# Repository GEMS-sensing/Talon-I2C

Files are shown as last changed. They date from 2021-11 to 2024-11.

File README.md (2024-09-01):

<!-- [![DOI](https://zenodo.org/badge/678911830.svg)](https://zenodo.org/doi/10.5281/zenodo.13377368) -->

# Talon-I2C
Talon daughterboard for [Flight data logger](https://github.com/GEMS-sensing/DFM_-_Flight?tab=readme-ov-file). Designed to interface with [Kestrel](https://github.com/GEMS-sensing/Project-Kestrel) main board. This board is designed to provide data logger with support to interface with I2C based sensors - a common interface for open source sensors.

# Repo Roadmap
#### [Documents](Documents/) 

General document and image storage for repo and README

#### [Hardware](Hardware/)

Current board files (Eagle), Bill of Materials (BoM), and other design documents

#### [Production](Production/)

Contains the various Gerber and pick and place files required to have the Printed Circuit Boards (PCBs) manufactured or populated 

#### [Software](Software/)

The software associated with the piece of hardware, this is usually diagnostic software used for verifying or investigating the hardware

<!-- #### [Mechanical](Mechanical/)

Mechanical design files and assembly documents -->

<!-- #### [Testing](Testing/)

Scripts and results from the testing process and development process. Contains more detailed information about documented issues among other testing. 
 -->

## Overview
* **Type:** Talon
* **Interfaces:** SDI-12
* **Release Version:** v2.1 - 2022/04/25

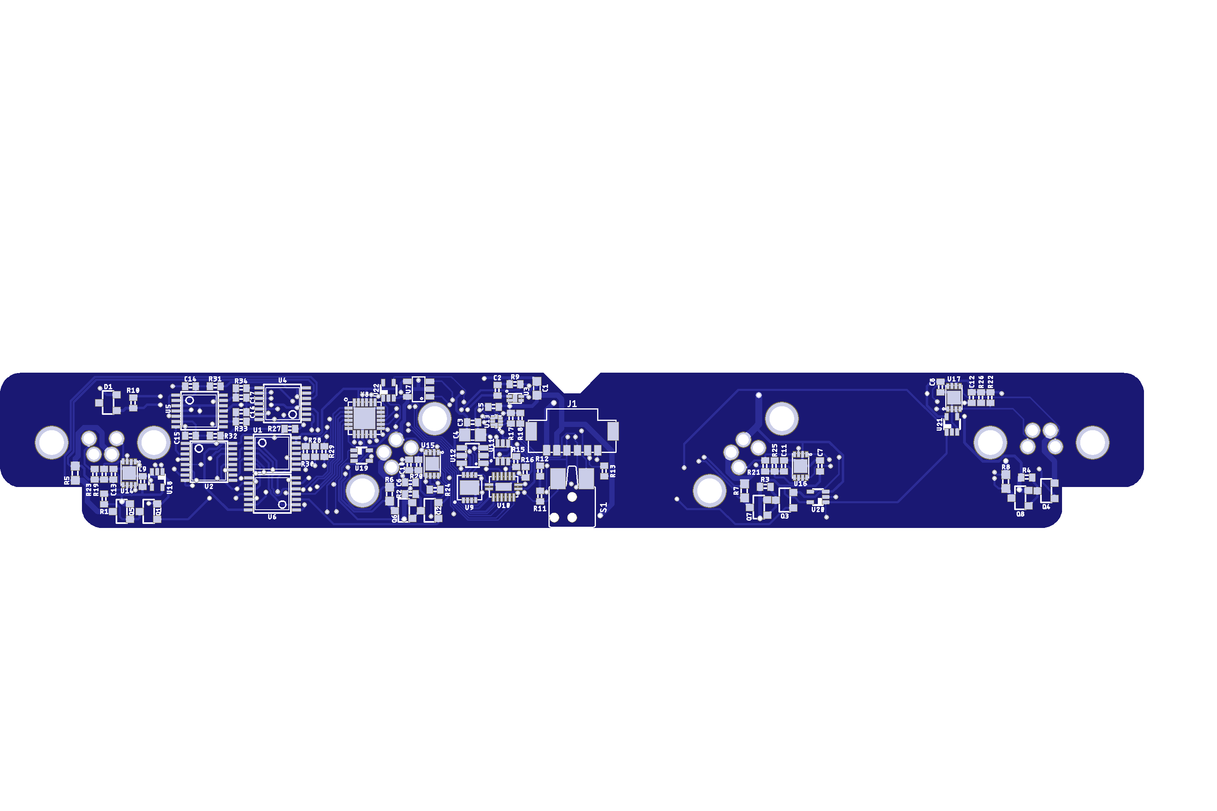
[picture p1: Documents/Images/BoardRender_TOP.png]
PCB render image, top


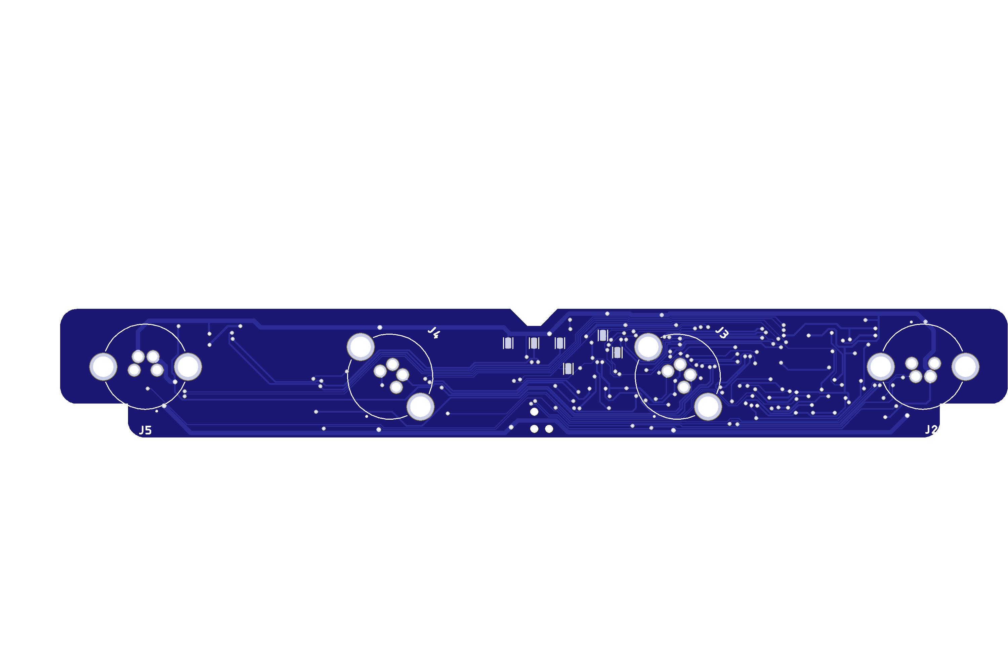
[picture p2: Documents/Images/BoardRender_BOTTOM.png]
PCB render image, bottom


<!-- ![Haar v0.0 - Bottom](Documents/Images/Haar_0v0_Bottom_Cropped.jpg) -->

## Features
### On-Board
* I2C ports (x4)
	* Isolated I2C bus for each port with line driver to deal with long, high capacitance sensor cables
* Port level current limit
	* Custom designed automatic current limit 
	* support for current and voltage measurement for each port
* Data and power control for each port
* Internal and external isolated I2C buses 
* EEPROM with UUID built in - can store additional values defined by firmware to track offsets, etc
* ESD protected inputs

<!-- ### Interface
* I<sup>2</sup>C
* M12 circular connector  -->

<!-- <picture>
  <source media="(prefers-color-scheme: dark)" srcset="Documents/Pinout_LIGHT.png">
  <img alt="Haar Connector Pinout" src="Documents/Pinout.png">
</picture> -->

<!-- ## Specifications
* **Voltage - Supply:** 3.3V
* **Voltage - Logic:** 3.3V
* **Input Current (Avg, 1s period): 30.95&mu;A @ 3.3V**
* **Input Current (Avg, 5s period): 107.43&mu;A @ 3.3V**
* **Input Current (Max): 0.45mA @ 3.3V**

#### Sensor
**Temperature** [^1]
* Range: -40 ~ 125°C 
* Accuracy: &plusmn; 0.2°C
* Repeatability: &plusmn; 0.04°C

**Pressure** [^2]
* Range: 300 ~ 1200 hPa  
* Accuracy: &plusmn; 1 hPa
* Repeatability: &plusmn; 0.06 hPa

**Humidity** [^1]
* Range: 0 ~ 100%
* Accuracy: &plusmn; 2%
* Repeatability: 0.08%

[^1]: [SHT31 Datasheet](https://sensirion.com/media/documents/213E6A3B/63A5A569/Datasheet_SHT3x_DIS.pdf)
[^2]: [DPS368 Datasheet](https://www.infineon.com/dgdl/Infineon-DPS368-DS-v01_00-EN.pdf?fileId=5546d46269e1c019016a0c45105d4b40) -->

<!-- ## Version History

`v0.0` - Initial primal version with screw terminal

`v0.1` - Initial 'hard mount' version, using M12 connector

`v1.0` - Removed pullup select[^3], added logic level buffer and voltage reg on input

`v1.1` - Moved via away from connector pads to prevent bridging when soldering 

`v2.0` - Fixed issue with address select jumper[^3] -->

<!-- ## Jumper Settings 

> [!IMPORTANT]
> Jumper settings valid for version `v2.0` and beyond[^3]

[^3]: See Errata

**Configuration Jumpers**
| Jumper | Purpose | Open | Closed | Default | 
| --- | --- | --- | --- | ----- |
| `JP1` | I<sup>2</sup>C Address Select | Base Address<sup>&dagger;</sup> | Alt Address<sup>&Dagger;</sup> | Open |

&dagger; SHT31 = `0x44`, DPS368 = `0x76`

&Dagger; SHT31 = `0x44`, DPS368 = `0x77`
 -->

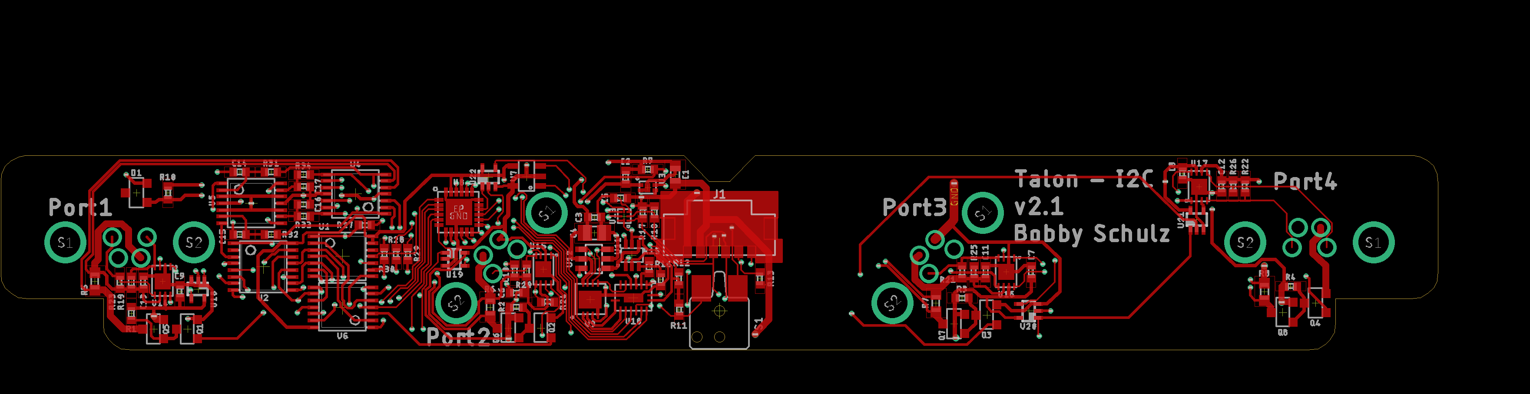
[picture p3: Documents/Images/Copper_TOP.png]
PCB trace CAD image, top


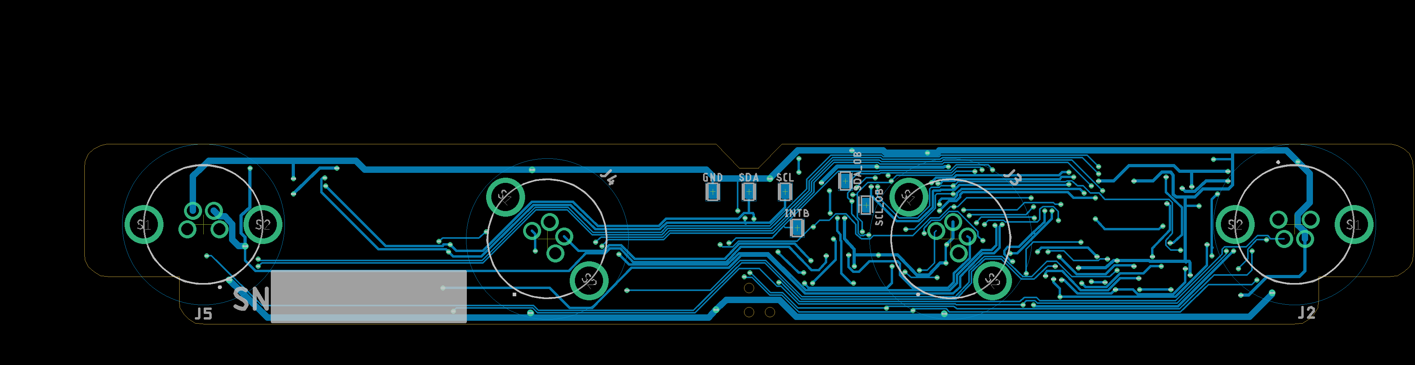
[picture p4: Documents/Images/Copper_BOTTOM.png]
PCB trace CAD, bottom


## Known Issues/Errata

None
<!-- #### Solder Jumper Stencil

**Version Affected:** All

**Issue:** Solar input does not support very low impedance sources (e.g. lead acid battery) - see details in issue [#20](https://github.com/GEMS-sensing/Project-Kestrel/issues/20)

**Workaround:** 

* Avoid use of low impedance batteries for input
* Include series impedance to prevent current spikes (not desirable)
* Perform board patch described in issue [#20](https://github.com/GEMS-sensing/Project-Kestrel/issues/20) -->

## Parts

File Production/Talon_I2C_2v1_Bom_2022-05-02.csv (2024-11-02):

Qty | Value | Device | Package | Parts | Description | DIGIKEY | DISP | MF | MPN | VALUE | VALUE_PART
11 | 0.1uF | C-EU0.1UFC0402 | C0402 | C2, C3, C5, C6, C7, C8, C9, C10, C11, C12, C13 | CAPACITOR, European symbol | 490-4759-1-ND |  | Murata | GCM155R71C104KA55D
3 | 100k | R-EU_100KR0402 | R0402 | R9, R12, R13 | RESISTOR, European symbol | 311-100KLRCT-ND |  | Yageo | RC0402FR-07100KL |  | 100k
17 | 10k | R-EU_10KR0402 | R0402 | R1, R2, R3, R4, R10, R15, R16, R17, R18, R19, R20, R21, R22, R23, R24, R25, R26 | RESISTOR, European symbol | 311-10.0KLRCT-ND |  | Yageo | RC0402FR-0710KL |  | 10k
1 | 10uF | C-EU10UFC0805 | C0805 | C4 | CAPACITOR, European symbol | 490-6473-1-ND |  | Murata | GRM21BR61C106KE15K
1 | 1M | R-EU_1MR0402 | R0402 | R11 | RESISTOR, European symbol | 311-1.00MLRCT-ND |  | Yageo | RC0402FR-071ML |  | 1M
8 | 1k | R-EU_1KR0402 | R0402 | R27, R28, R29, R30, R31, R32, R33, R34 | RESISTOR, European symbol | 311-1.00KLRCT-ND |  | Yageo | RC0402FR-071KL |  | 1k
1 | 1uF | C-EU1UFC0603 | C0603 | C1 | CAPACITOR, European symbol | 587-1251-1-ND |  | Yaiyo Yuden | EMK107BJ105KA-T
1 | 2.048V | LM40402.048 | SOT23-3 | D1 | LM4040 - Precision Micropower Shunt Voltage Referance | LM4040CIM3-2.0/NOPBCT-ND |  | TI | LM4040CIM3-2.0/NOPB
4 | 2N7002 | MOSFET-NCH-2N7002P | SOT23-3 | Q1, Q2, Q3, Q4 | N-channel MOSFET | 1727-4692-1-ND |  | Nexperia | 2N7002P | 215 | 2N7002
1 | 74HC4852 | 74HC4852 | VQFN-16 | U10 | 74HC4852 - Analog Multiplexer, Dual 4-Channel (1:4 x 2) | 1727-7953-1-ND | 74HC4852 | Nexperia | 74HC4852BQ-Q100 | 11
4 | 82m | R-EU_0.082R0603 | R0603 | R5, R6, R7, R8 | RESISTOR, European symbol | 408-1446-1-ND |  | Susumu | RL0816T-R082-F |  | 82m
4 | AO3419 | MOSFET-PCH-AO3419 | SOT23-3 | Q5, Q6, Q7, Q8 | P-channel MOSFET | 785-1013-1-ND |  | Alpha and Omega | AO3419 | AO3419
1 | AT24MAC602SOT23 | AT24MAC602SOT23 | SOT23-5 | U7 | AT24MACx02 - 2kb I2C Serial EEPROM with EUI serial number | AT24MAC602-STUM-TCT-ND | AT24MAC602 | Microchip | AT24MAC602-STUM-T
1 | CD4044 | CD4044 | TSSOP16 | U2 | CD404x - S-R Latch, Quad | 296-31499-1-ND | CD4044 | TI | CD4044BPWR
4 | CONN_I2C_LOGGER | CONN_I2C_LOGGER | 1X04_M8_TE_T404103_BOARDLOCK | J2, J3, J4, J5 | GEMS Connector for I2C Devices - Logger Side | A126815-ND | Logger | TE | T4041037041-000
1 | CONN_TALON_REMOTE | CONN_TALON_REMOTE | 1X06_MICROLOCKPLUS | J1 | GEMS Connector for Talon Interface | 900-2059570671CT-ND | Remote | Molex | 2059570671
4 | DNP | C-EU0.1UFC0402 | C0402 | C14, C15, C16, C17 | CAPACITOR, European symbol | DNP |  | N/A | DNP
1 | ESE-22MH | SPSTESE-22MH | ESE-22MH | S1 | Generic SPST (Single Pole Single Throw) Switch | P13584SCT-ND |  | Panasonic | ESE-22MH24 | ESE-22MH
1 | FXMAR2102UMLP | FXMAR2102UMLP | UQFN-8_1.4X1.2 | U13 | FXMAR2102 - 2 Channel Bidirectional Voltage Level Translator for I2C Applications | FXMAR2102UMX-F106CT-ND | FXMAR2102 | OnSemi | FXMAR2102UMX-F106
1 | INA4180A2 | INA4180A2 | TSSOP14 | U4 | INA4180 - Analog Output Current Sense Amplifier | 296-49095-1-ND | INA4180A2 | TI | INA4180A2IPWR
1 | MAX9034TSSOP | MAX9034TSSOP | TSSOP14 | U5 | MAX9034 - Ultra-Small nanoPower Single Comparator , Quad | MAX9034AUD+CT-ND | MAX9034 | Maxim | MAX9034AUD+T
1 | MCP3421A3 | MCP3421A3 | SOT23-6L | U12 | MCP342* - Sigma Delta ADC | MCP3421A3T-E/CHCT-ND | MCP3421 | Microchip | MCP3421A3T-E/CH
1 | PCA9536DFN | PCA9536DFN | DFN_8_3X3 | U9 | PCA9536 - I2C I/O Expander, 4 bit, 5V tollerant | 568-4079-1-ND |  | NXP | PCA9536TK | 118
4 | PCA9617WSON | PCA9617WSON | WSON-8_2X3 | U14, U15, U16, U17 | PCA9617A - Level translating I2C Bus Repeater | 568-10953-1-ND |  | NXP | PCA9617ATPZ
1 | PCAL9535AQFN | PCAL9535AQFN | QFN24 | U8 | PCAL95*5A - I2C I/O Expander, 16 bit wtih interrupt and agile IO | 568-9947-1-ND | PCAL9535A | NXP | PCAL9535AHF | 128
1 | SIP32431TDFN | SIP32431TDFN | TDFN_4 | U3 | SiP3243x - Ultra Low Leakage Load Switch with Reverse Blocking | SIP32431DNP3-T1GE4CT-ND | SIP32431 | Vishay | SIP32431DNP3-T1GE4
1 | SN74AC08 | SN74AC08 | TSSOP14 | U6 | SN74AC08 - AND, 4 Element, 2 Input | 296-4292-1-ND |  | TI | SN74AC08PWR
4 | SN74AUP1G08DCK | SN74AUP1G08DCK | DCK_R-PDSO-G5 | U18, U19, U20, U21 | SN74AUP1G08 - AND, 1 Element, 2 Input | 296-19075-1-ND |  | TI | SN74AUP1G08DCKR
1 | SN74AUP1G32DCK | SN74AUP1G32DCK | DCK_R-PDSO-G5 | U22 | SN74x1G32 - Single OR Gate | 296-18714-1-ND | SN74AUP1G32 | TI | SN74AUP1G32DCKR
1 | SN74HC04 | SN74HC04 | TSSOP14 | U1 | SN74HC04 - NOT, 4 Element, 1 Input - Hex Inverter | 296-8208-1-ND |  | TI | SN74HC04PWR
1 | SN74LVC1G3157SC70 | SN74LVC1G3157SC70 | DCK_R-PDSO-G6 | U11 | SN74LVC1G3157 - SPDT Analog Switch | 296-14909-1-ND | SN74LVC1G3157 | TI | SN74LVC1G3157DCKR
6 | TESTPOINTRCU | TESTPOINTRCU | TESTPOINT_0603 | TP1, TP2, TP3, TP4, TP5, TP6 | Test Point | A106145CT-ND |  | TE Connectivity | RCU-0C

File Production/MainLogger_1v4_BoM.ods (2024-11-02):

Qty | Value | Device | Package | Parts | Description | DIGIKEY | DISP | MF | MPN | PROD_ID | SF_ID | VALUE | VALUE_PART
5 |  | FERRITE_BEAD1KS0402 | R0402 | FB1, FB2, FB3, FB4, FB5 | Genaric Ferrite Bead | 490-4003-1-ND |  | Murata | BLM15HD102SN1D
1 |  | SN74LVC1G14DCK | DCK_R-PDSO-G5 | U32 | SN74x1G14 - Single Schmitt Triger Inverter | 296-11608-1-ND |  | TI | SN74LVC1G14DCKR
31 | 0.1uF | C-EU0.1UFC0402 | C0402 | C1, C4, C5, C6, C7, C8, C9, C10, C12, C14, C20, C38, C39, C41, C43, C44, C45, C46, C48, C49, C50, C51, C52, P1:C1, P1:C5, P2:C1, P2:C5, P3:C1, P3:C5, P4:C1, P4:C5 | CAPACITOR, European symbol | 490-4759-1-ND |  | Murata | GCM155R71C104KA55D
1 | 0.47uH | INDUCTOR_MAPI_4.1X4.1 | WE-MAPI(4.1X4.1) | L2 | Genaric Inductor | 732-744383560047HTCT-ND |  | Wurth | 744383560047HT
1 | 0R | R-EU_0.0R0402 | R0402 | R24 | RESISTOR, European symbol | 311-0.0JRCT-ND |  | Yageo | RC0402JR-070RL |  |  |  | 0
1 | 1.5uF | C-EU1.5UFC0805 | C0805 | C31 | CAPACITOR, European symbol | 399-4930-1-ND |  | Kemet | C0805C155K4RACTU
1 | 10 | R-EU_10R0402 | R0402 | R48 | RESISTOR, European symbol | A129603CT-ND |  | TE | CRGCQ0402F10R |  |  |  | 10
10 | 100k | R-EU_100KR0402 | R0402 | R8, R14, R15, R21, R30, R31, R47, R49, R53, R57 | RESISTOR, European symbol | 311-100KLRCT-ND |  | Yageo | RC0402FR-07100KL |  |  |  | 100k
1 | 100pF | C-EU100PFC0402 | C0402 | C26 | CAPACITOR, European symbol | 311-1024-1-ND |  | Yageo | CC0402JRNPO9BN101
5 | 100uF | CTANT_EU1411 | C1411_TANT | C28, P1:C4, P2:C4, P3:C4, P4:C4 | Genaric Tantalum Capacitor | 478-5231-1-ND |  | Kyocera AVX | TPSB107M010R0400
7 | 10k | R-EU_10KR0402 | R0402 | R22, R29, R33, R39, R45, R46, R65 | RESISTOR, European symbol | 311-10.0KLRCT-ND |  | Yageo | RC0402FR-0710KL |  |  |  | 10k
3 | 10m | R-EU_0.01R0805 | R0805 | R6, R7, R17 | RESISTOR, European symbol | CRF0805-FZ-R010ELFCT-ND |  | Bourns | CRF0805-FZ-R010ELF
2 | 10nF | C-EU10NFC0402 | C0402 | C21, C25 | CAPACITOR, European symbol | 490-4762-1-ND |  | Murata | GCM155R71H103KA55D
2 | 10uF | C-EU10UFC0805 | C0805 | C23, C29 | CAPACITOR, European symbol | 490-5523-1-ND |  | Murata | GRM21BR61E106KA73L
3 | 10uF | C-EU10UFC0805 | C0805 | C35, C36, C37 | CAPACITOR, European symbol | 490-6473-1-ND |  | Murata | GRM21BR61C106KE15K
1 | 11k | R-EU_11KR0402 | R0402 | R58 | RESISTOR, European symbol | 311-11.0KLRCT-ND |  | Yageo | RC0402FR-0711KL |  |  |  | 11k
1 | 13.3k | R-EU_13.3KR0402 | R0402 | R3 | RESISTOR, European symbol | YAG2974CT-ND |  | Yageo | RC0402FR-0713K3L |  |  |  | 13.3k
2 | 130k | R-EU_130KR0402 | R0402 | R43, R56 | RESISTOR, European symbol | YAG2969CT-ND |  | Yageo | RC0402FR-07130KL |  |  |  | 130k
1 | 150k | R-EU_150KR0402 | R0402 | R38 | RESISTOR, European symbol | 311-150KLRCT-ND |  | Yageo | RC0402FR-07150KL |  |  |  | 150k
12 | 1M | R-EU_1MR0402 | R0402 | R1, R2, R11, R19, R26, R32, R35, R40, R41, R42, R54, R55 | RESISTOR, European symbol | 311-1.00MLRCT-ND |  | Yageo | RC0402FR-071ML |  |  |  | 1M
9 | 1k | R-EU_1KR0402 | R0402 | P1:R2, P1:R3, P2:R2, P2:R3, P3:R2, P3:R3, P4:R2, P4:R3, R12 | RESISTOR, European symbol | 311-1.00KLRCT-ND |  | Yageo | RC0402FR-071KL |  |  |  | 1k
1 | 1nF | C-EU1NFC0402 | C0402 | C19 | CAPACITOR, European symbol | 490-3244-1-ND |  | Murata | GRM1555C1H102JA01D
12 | 1uF | C-EU1UFC0603 | C0603 | C11, C15, C22, C27, C40, C47, C53, C54, P1:C3, P2:C3, P3:C3, P4:C3 | CAPACITOR, European symbol | 587-2984-1-ND |  | Yaiyo Yuden | TMK107B7105KA-T
2 | 1uH | INDUCTOR_MAIA_4.1X4.1 | WE-MAIA(4.1X4.1) | L1, L3 | Genaric Inductor | 732-11310-1-ND |  | Wurth | 78438356010
6 | 2.2uF | C-EU2.2UFC0603 | C0603 | C2, C3, P1:C2, P2:C2, P3:C2, P4:C2 | CAPACITOR, European symbol | 1276-1183-1-ND |  | Samsung | CL10A225KQ8NNNC
2 | 2.7k | R-EU_2.7KR0402 | R0402 | R23, R37 | RESISTOR, European symbol | CR0402-FX-2701GLFCT-ND |  | Bourns | CR0402-FX-2701GLF |  |  |  | 2.7k
1 | 20k | R-EU_20KR0402 | R0402 | R20 | RESISTOR, European symbol | CR0402-FX-2002GLFCT-ND |  | Bourns | CR0402-FX-2002GLF |  |  |  | 20k
10 | 220R | R-EU_220R0402 | R0402 | R27, R28, R59, R60, R61, R62, R63, R64, R66, R67 | RESISTOR, European symbol | A129619CT-ND |  | TE | CRGCQ0402F220R |  |  |  | 220
1 | 220uF | CTANT_EU2917 | C2917 | C30 | Genaric Tantalum Capacitor | 399-9744-1-ND |  | Kemet | T491D227M010AT
5 | 22uF | C-EU22UFC0805 | C0805 | C13, C16, C17, C18, C34 | CAPACITOR, European symbol | 490-9952-1-ND |  | Murata | GRM219R61C226ME15L
2 | 27R | R-EU_27R0402 | R0402 | R9, R10 | RESISTOR, European symbol | YAG3086CT-ND |  | Yageo | RC0402FR-0727RL |  |  |  | 27
1 | 2k | R-EU_2KR0402 | R0402 | R4 | RESISTOR, European symbol | 311-2KLRCT-ND |  | Yageo | RC0402FR-072KL |  |  |  | 2k
5 | 2m | R-EU_0.002R0805 | R0805 | R5, R13, R25, R34, R36 | RESISTOR, European symbol | RHM.002AJCT-ND |  | Rohm | PMR10EZPFV2L00
1 | 30k | R-EU_30KR0402 | R0402 | R44 | RESISTOR, European symbol | YAG3474CT-ND |  | Yageo | AC0402FR-0730KL |  |  |  | 30k
1 | 39pF | C-EU39PFC0402 | C0402 | C24 | CAPACITOR, European symbol | 399-1018-1-ND |  | Kemet | C0402C390J5GAC7867
1 | 4.7uF | C-EU4.7UFC0805 | C0805 | C33 | CAPACITOR, European symbol | 399-7415-1-ND |  | Kemet | C0805C475K4RACTU
1 | 470k | R-EU_470KR0603 | R0603 | R16 | RESISTOR, European symbol | 311-470KGRCT-ND |  | Yageo | RC0603JR-07470KL |  |  |  | 470k
1 | 47nF | C-EU47NFC0402 | C0402 | C32 | CAPACITOR, European symbol | 490-3254-1-ND |  | Murata | GRM155R71E473KA88D
1 | 47pF | C-EU47PFC0402 | C0402 | C42 | CAPACITOR, European symbol | 490-10670-1-ND |  | Murata | GCM1555C1H470JA16D
4 | 5.6k | R-EU_5.6KR0402 | R0402 | R50, R51, R52, R68 | RESISTOR, European symbol | 311-5.6KLRCT-ND |  | Yageo | RC0402FR-075K6L |  |  |  | 5.6k
1 | 750R | R-EU_750R0603 | R0603 | R18 | RESISTOR, European symbol | 311-750HRCT-ND |  | Yageo | RC0603FR-07750RL |  |  |  | 750
4 | AP2411 | AP2411 | MSOP_8EP | P1:U4, P2:U4, P3:U4, P4:U4 | AP24x1 - Current Limit Load Switch with Latch-Off | AP2411MP-13DICT-ND | AP2411 | Diodes Inc | AP2411MP-13
1 | BAT54C | DIODE_CCBAT54CSOT23 | SOT23-3 | D4, D6 | Dual Diode, Common Cathode | BAT54CLT1GOSCT-ND |  | ON Semiconductor | BAT54CLT1G
1 | BAT54WS | DIODE_SCHOTTKYSOD-323 | SOD323-R | D9, D19 | Generic Shottky Diode | BAT54WS-TPCT-ND |  | Micro Commercial | BAT54WS-TP
1 | BATTERY_COINML621 | BATTERY_COINML621 | ML621S | BT1 | Coin Cell Battery Holder | P044-ND |  | Panasonic | ML-621S/DN
1 | BQ25616 | BQ25616 | QFN24_POWER | U16 | BQ25616 - Buck Battery Charger Standalone 1-Cell 3.0-A Buck Battery Charger with Power Path and 1.2-A | 296-BQ25616RTWRCT-ND |  | TI | BQ25616RTWR
1 | B_SERIES_M.2EKEY_3042 | B_SERIES_M.2EKEY_3042 | PARTICLE_M.2EKEY | $3_190_$_2021-12-10_02-09-55 | Particle B Series SoM | A115904CT-ND |  | TE | 2199230-4
1 | CDBA3100 | DIODE_SCHOTTKYDO-214AC | DO214AC | D3 | Generic Shottky Diode | 641-1747-1-ND |  | Comchip | CDBA3100-HF
1 | CLVBA-FKA | CLVBA-FKA | CLVBA-FKA | D8 | Cree RGB LED, Small Package, Common Anode, CLVBA-FKA | CLVBA-FKA-CAEDH8BBB7A363CT-ND |  | Cree | CLVBA-FKA-CAEDH8BBB7A363
2 | DMG3404 | MOSFET-NCH-DMG3404L | SOT23-3 | Q1, Q4 | N-channel MOSFET | DMG3404L-7DICT-ND |  | Diodes Incorporated | DMG3404L-7 |  |  | DMG3404
1 | FPF2195BUCX | FPF2195BUCX | WCSP_6 | U31 | FPF219x - Load Switch, with Adjustable Current Limit and Fault Indicator | FPF2195BUCXCT-ND | FPF2195BUCX | onsemi | FPF2195BUCX
4 | FSA2258 | FSA2258 | MICROPAK_10 | P1:U3, P2:U3, P3:U3, P4:U3 | FSA2258 - Low Voltage, Dual SPDT Analog Switch | FSA2258L10XCT-ND | FSA2258 | OnSemi | FSA2258L10X
7 | FXMAR2102UMLP | FXMAR2102UMLP | UQFN-8_1.4X1.2 | P1:U2, P2:U2, P3:U2, P4:U2, U1, U9, U28 | FXMAR2102 - 2 Channel Bidirectional Voltage Level Translator for I2C Applications | FXMAR2102UMX-F106CT-ND | FXMAR2102 | OnSemi | FXMAR2102UMX-F106
1 | HALL_EFFECT_SI7201 | HALL_EFFECT_SI7201 | SOT23-3 | U22 | General Hall Effect Sensor | 336-4121-1-ND | Si7201 | Silicon Labs | SI7201-B-05-IVR
4 | LEDAMBER0603 | LEDAMBER0603 | LED_0603 | D7, D11, D14, D17 | Genaric LED | 732-150060AS75000CT-ND |  | Wurth | 150060AS75000
5 | LEDGREEN0603 | LEDGREEN0603 | LED_0603 | D5, D10, D13, D15, D16 | Genaric LED | 732-4971-1-ND |  | Wurth | 150060GS75000
3 | LEDRED0603 | LEDRED0603 | LED_0603 | D1, D12, D18 | Genaric LED | 732-4978-1-ND |  | Wurth | 150060RS75000
1 | LP59073.3VYKE | LP59073.3VYKE | YKE0004 | U14 | LP5907 - Ultra Low Noise, Low IQ LDO | 296-39067-1-ND | LP5907 | TI | LP5907UVX-3.3/NOPB
1 | LTC4412S6 | LTC4412S6 | SOT23-6L | U12 | LTC4412 - Low Loss PowerPath Controller (ORing FET Controller) | LTC4412ES6#TRPBFCT-ND |  | LT | LTC4412ES6#TRPBF
1 | MAX-M8W | MAX-M8W | MAX-M8 | U20 | MAX-M8* GPS Unit - GNSS Module | 672-MAX-M8W-0CT-ND | MAX-M8W | U-Blox | MAX-M8W-0
1 | MB85RC | MB85RC | SO08 | U27 | MB85RCx - FRAM I2C Memory | 865-1269-1-ND | MB85RC512 | Fujitsu | MB85RC512TPNF-G-JNERE1
2 | MCP23018QFN | MCP23018QFN | QFN24 | U18, U19 | MCP23018 - I2C I/O Expander, 16 bit wtih interrupt and reset | MCP23018T-E/MJCT-ND |  | TI | MCP23018T-E/MJ
1 | MCP79412SOIC | MCP79412SOIC | SO08 | U21 | MCP794xx - Battery Backed I2C Real Time Clock (RTC) with SRAM (EEPROM*) and Protected EERPOM | MCP79412-I/SN-ND | MCP79412 | Microchip | MCP79412-I/SN
1 | MIC22602 | MIC22602 | QFN24_POWER | U15 | MIC2260x - High Efficiency Synchronous Buck Converter | 576-3645-1-ND | MIC22602 | Microchip | MIC22602YML-TR
1 | MICROSDMOLEX_503182 | MICROSDMOLEX_503182 | MICROSD_MOLEX_5031821852 | SD1 | Micro-SD / Transflash card holder with SPI pinout | WM12834CT-ND |  | Molex | 5031821852
1 | MMC5633 | MMC5633 | BGA_4 | U3 | MMC5633 - High Performance 3 Axis Magnetic Sensor (Compass) | 1267-MMC5633NJLCT-ND | MMC5633 | Memsic | MMC5633NJL
2 | MOSFET_PCH-DMP3036SFG | MOSFET_PCH-DMP3036SFG | POWERDI3333-8 | Q2, Q3 | P-channel MOSFETs | DMP3036SFG-7DICT-ND |  | Diodes Incorporated | DMP3036SFG-7
1 | MXC6655 | MXC6655 | LGA-12_2X2 | U4 | MXC6655 - 3-axis Digital Accelerometer (I2C) | 1267-MXC6655XACT-ND | MXC6655 | Memsic | MXC6655XA
2 | NX2301P | MOSFET-PCH-NX2301P | SOT23-3 | Q5, Q6 | P-channel MOSFET | 1727-1148-1-ND |  | Nexperia | NX2301P | 215 |  |  | NX2301P
2 | PAC1934QFN | PAC1934QFN | QFN16 | U5, U6 | PAC1934 - High Side Current/Power Monitor with I2C Interface and Accumulator | PAC1934T-I/JQCT-ND |  | Microchip | PAC1934T-I/JQ
1 | PCA9634QFN | PCA9634QFN | QFN20_5X5 | U23 | PCA9634 - I2C LED Driver, 8 Channel | 568-8717-1-ND | PCA9634 | NXP | PCA9634BS | 118
1 | RCLAMP3654 | RCLAMP3654 | DFN_6_1.6X1.6 | D2 | USB ESD Clamping Diode Array | RCLAMP3654PATCTCT-ND | RClamp3654 | Semtech | RCLAMP3654PATCT
1 | SHT40 | SHT40 | SHT4X | U7 | SHT4x - Digital Humidity and Temperature Sensor | 1649-SHT40-AD1B-R3CT-ND | SHT40 | Sensirion | SHT40-AD1B-R3
1 | SIT1552 | SIT1552 | LD-4 | U29 | SiT1552 - Ultra Low Power 32.768 kHz MEMS TCXO | 1473-1242-1-ND | SiT1552 | SiTime | SIT1552AI-JF-DCC-32.768D
5 | SN74AUP1G08DCK | SN74AUP1G08DCK | DCK_R-PDSO-G5 | P1:U1, P2:U1, P3:U1, P4:U1, U8 | SN74AUP1G08 - AND, 1 Element, 2 Input | 296-19075-1-ND |  | TI | SN74AUP1G08DCKR
1 | SN74AUP3G34DCU | SN74AUP3G34DCU | DCU_(R-PDSO-G8) | U10 | SN74AUP3G34 - Logic Buffer | 296-25595-1-ND |  | TI | SN74AUP3G34DCUR
1 | SN74LVC1G17DCK | SN74LVC1G17DCK | DCK_R-PDSO-G5 | U24 | SN74LVC1G17 - Single Schmitt Trigger Logic Buffer | 296-11934-1-ND | SN74LVC1G17 | TI | SN74LVC1G17DCKR
1 | SPDT7103K2CWAV2 | SPDT7103K2CWAV2 | 7103K2CWAV2 | S3 | Genaric SPDT switch | 7103K2CWAV2BE-ND |  | C&K | 7103K2CWAV2BE
2 | TCK111G | TCK111G | WCSP_6 | U11, U30 | TCK11x - Load Switch, with Reverse Current Blocking, Output Discharge (TCK112G Only) | TCK111GLFCT-ND | TCK111G | Toshiba | TCK111G | LF
1 | TCR2LE31ESV | TCR2LE31ESV | SOT-553 | U13 | TCR2Lyxx - Ultra Low Quiescent Current, Low Dropout Linear Regulator with Enable | TCR2LE31LMCT-ND | TCS2LE31 | Toshiba | TCR2LE31 | LM
7 | TESTPOINTRCU | TESTPOINTRCU | TESTPOINT_0603 | TP1, TP2, TP5, TP6, TP7, TP8, TP9 | Test Point | A106145CT-ND |  | TE Connectivity | RCU-0C
2 | TPL5010DDC | TPL5010DDC | DDC_R-PDSO-G6 | U25, U26 | TPL5010 - Nano-Power System Timer with Watchdog Functionality | 296-38829-1-ND |  | TI | TPL5010DDCT
1 | TPS61282D | TPS61282D | YFP0016 | U17 | TPS6128x - Low/Wide Voltage Battery Front-End DC/DC Converter, Logic Interface | 296-50826-1-ND | TPS61282D | TI | TPS61282DYFFT
1 | VEML3328 | VEML3328 | VEML6075 | U2 | VEML3328 - RGBCIR Color Sensor with I2C Interface | 751-VEML3328CT-ND | VEML3328 | Vishay | VEML3328

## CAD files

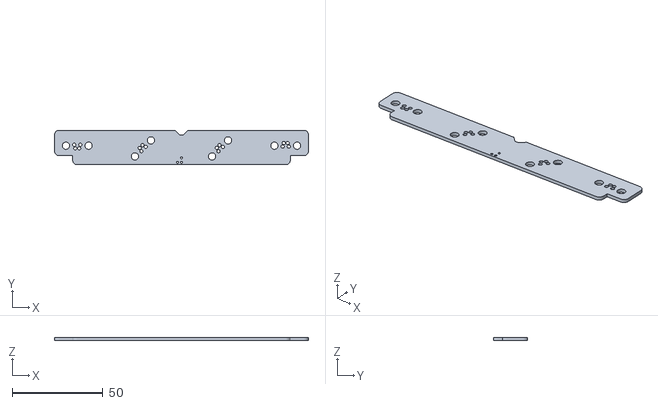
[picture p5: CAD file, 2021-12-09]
Hardware/Talon_I2C_1v1.STL
140.0 x 19.0 x 1.57

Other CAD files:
Hardware/Talon_I2C_1v1.dxf

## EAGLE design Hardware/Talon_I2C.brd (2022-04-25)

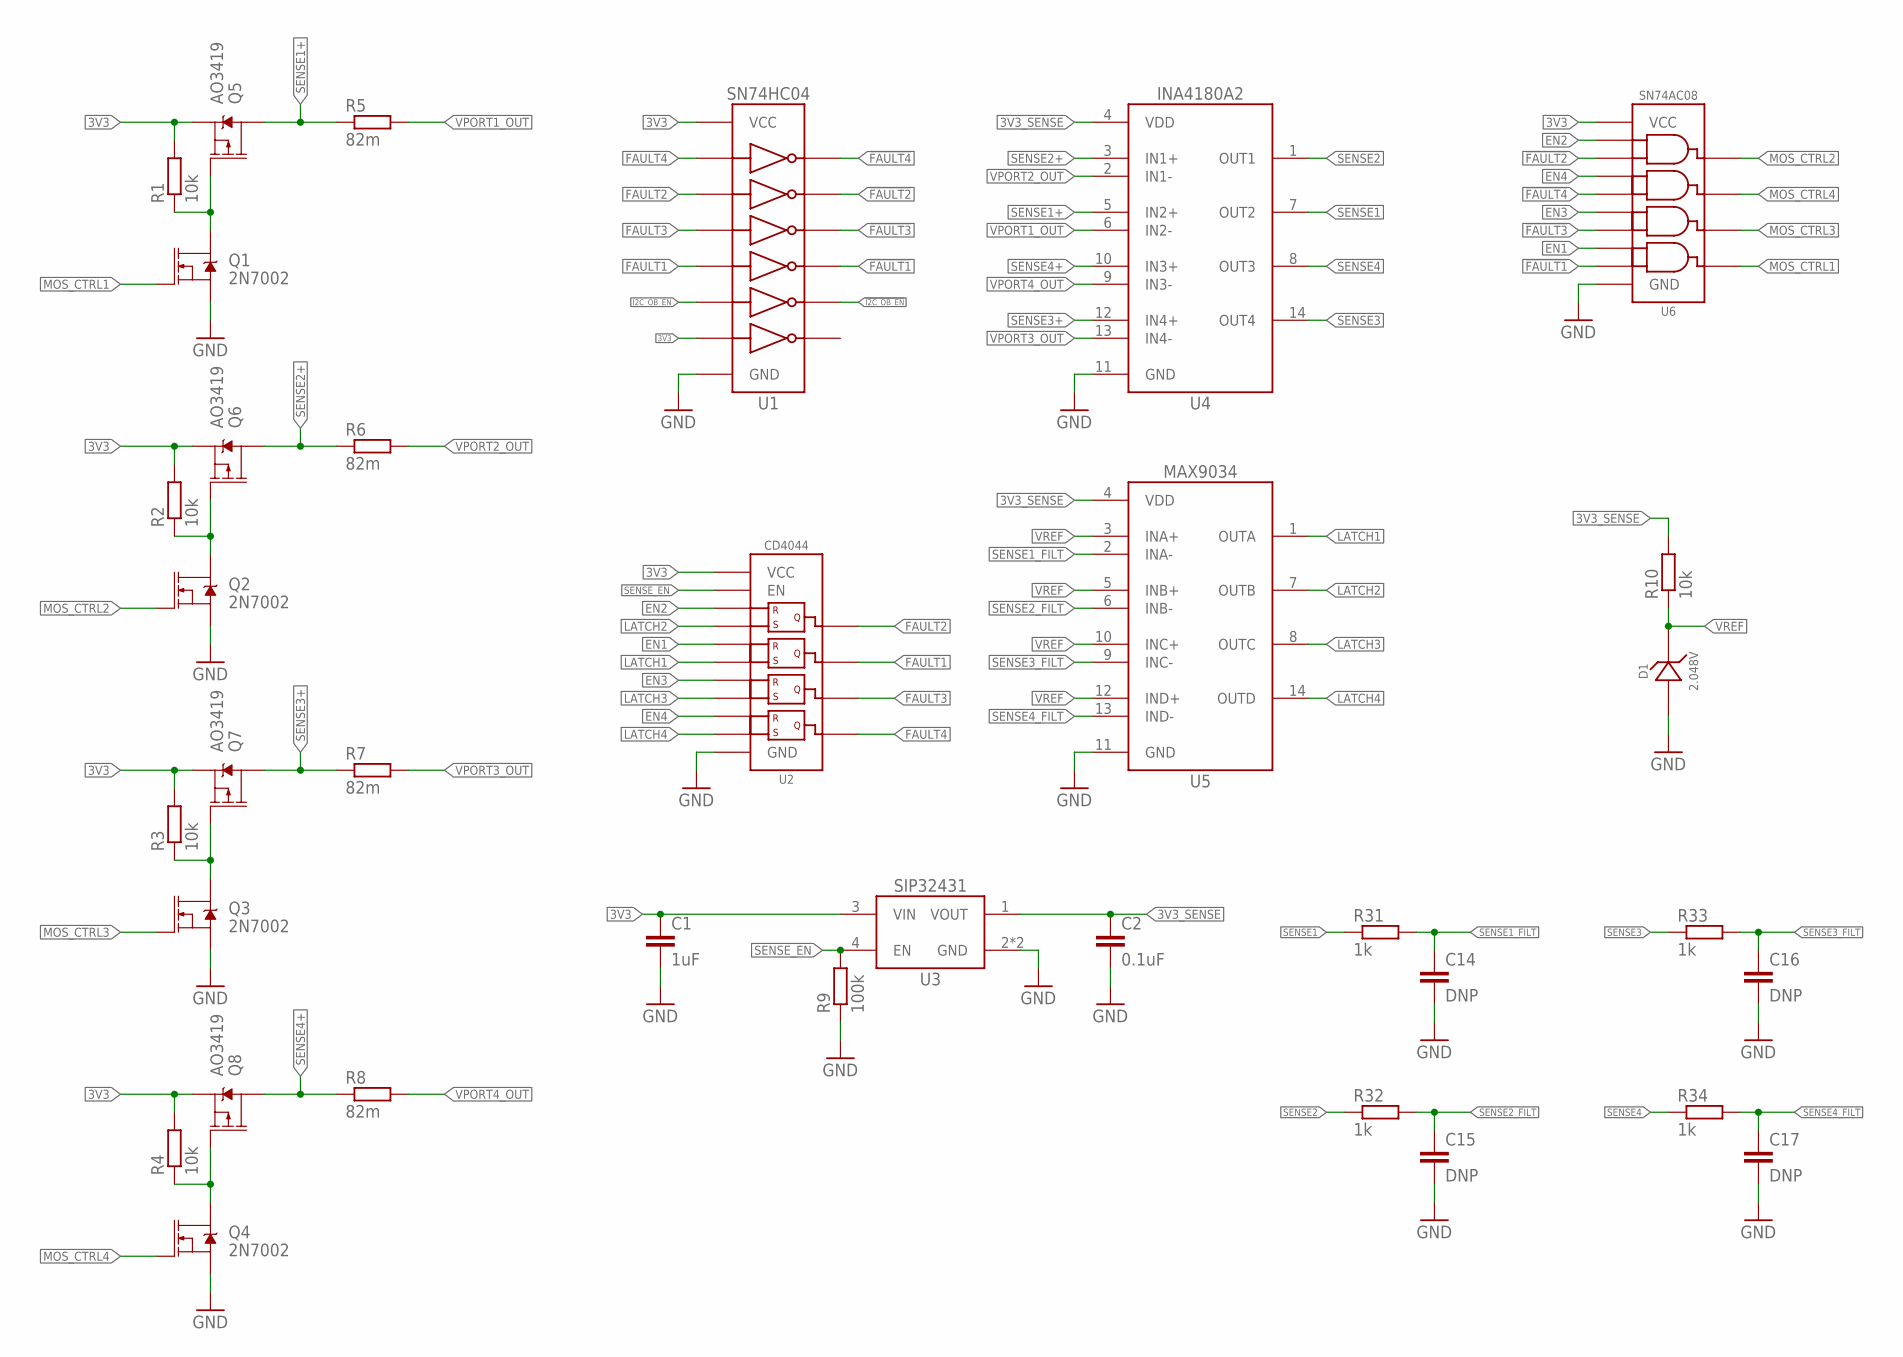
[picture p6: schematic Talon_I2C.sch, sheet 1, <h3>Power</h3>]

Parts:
C1: 1uF; C0603
C2: 0.1uF; C0402
C14, C15, C16, C17: DNP; C0402; MPN DNP; DIGIKEY DNP
D1: 2.048V; SOT23-3
Q1, Q2, Q3, Q4: 2N7002; SOT23-3
Q5, Q6, Q7, Q8: AO3419; SOT23-3
R1, R2, R3, R4, R10: 10k; R0402
R5, R6, R7, R8: 82m; R0603
R9: 100k; R0402
R31, R32, R33, R34: 1k; R0402
U1: SN74HC04; TSSOP14
U2: CD4044; TSSOP16
U3: SIP32431TDFN; TDFN_4
U4: INA4180A2; TSSOP14
U5: MAX9034TSSOP; TSSOP14
U6: SN74AC08; TSSOP14

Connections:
3V3: C1.1, Q5.2 (S), Q6.2 (S), Q7.2 (S), Q8.2 (S), R1.2, R2.2, R3.2, R4.2, U1.13 (A6), U1.14 (VCC), U2.16 (VCC), U3.3 (VIN), U6.14 (VCC); also elsewhere on the board
3V3_SENSE: C2.1, R10.2, U3.1 (VOUT), U4.4 (VDD), U5.4 (VDD)
!FAULT1: U1.8 (Y4), U6.13 (B4)
!FAULT2: U1.4 (Y2), U6.2 (B1)
!FAULT3: U1.6 (Y3), U6.10 (B3)
!FAULT4: U1.2 (Y1), U6.5 (B2)
!I2C_OB_EN: U1.10 (Y5); also elsewhere on the board
EN1: U2.6 (R2), U6.12 (A4); also elsewhere on the board
EN2: U2.4 (R1), U6.1 (A1); also elsewhere on the board
EN3: U2.12 (R3), U6.9 (A3); also elsewhere on the board
EN4: U2.14 (R4), U6.4 (A2); also elsewhere on the board
FAULT1: U1.9 (A4), U2.9 (Q2); also elsewhere on the board
FAULT2: U1.3 (A2), U2.13 (Q1); also elsewhere on the board
FAULT3: U1.5 (A3), U2.10 (Q3); also elsewhere on the board
FAULT4: U1.1 (A1), U2.1 (Q4); also elsewhere on the board
GND: C1.2, C2.2, C14.2, C15.2, C16.2, C17.2, D1.2 (A), Q1.2 (S), Q2.2 (S), Q3.2 (S), Q4.2 (S), R9.1, U1.7 (GND), U2.8 (GND), U3.2 (GND), U3.EP (GND), U4.11 (GND), U5.11 (GND), U6.7 (GND); also elsewhere on the board
I2C_OB_EN: U1.11 (A5); also elsewhere on the board
LATCH1: U2.7 (S2), U5.1 (OUTA)
LATCH2: U2.3 (S1), U5.7 (OUTB)
LATCH3: U2.11 (S3), U5.8 (OUTC)
LATCH4: U2.15 (S4), U5.14 (OUTD)
MOS_CTRL1: Q1.1 (G), U6.11 (Y4)
MOS_CTRL2: Q2.1 (G), U6.3 (Y1)
MOS_CTRL3: Q3.1 (G), U6.8 (Y3)
MOS_CTRL4: Q4.1 (G), U6.6 (Y2)
unnamed: Q2.3 (D), Q6.1 (G), R2.1
unnamed: Q1.3 (D), Q5.1 (G), R1.1
unnamed: Q3.3 (D), Q7.1 (G), R3.1
unnamed: Q4.3 (D), Q8.1 (G), R4.1
SENSE1: R31.1, U4.7 (OUT2); also elsewhere on the board
SENSE1+: Q5.3 (D), R5.1, U4.5 (IN2+)
SENSE1_FILT: C14.1, R31.2, U5.2 (INA-)
SENSE2: R32.1, U4.1 (OUT1); also elsewhere on the board
SENSE2+: Q6.3 (D), R6.1, U4.3 (IN1+)
SENSE2_FILT: C15.1, R32.2, U5.6 (INB-)
SENSE3: R33.1, U4.14 (OUT4); also elsewhere on the board
SENSE3+: Q7.3 (D), R7.1, U4.12 (IN4+)
SENSE3_FILT: C16.1, R33.2, U5.9 (INC-)
SENSE4: R34.1, U4.8 (OUT3); also elsewhere on the board
SENSE4+: Q8.3 (D), R8.1, U4.10 (IN3+)
SENSE4_FILT: C17.1, R34.2, U5.13 (IND-)
SENSE_EN: R9.2, U2.5 (EN), U3.4 (EN); also elsewhere on the board
VPORT1_OUT: R5.2, U4.6 (IN2-); also elsewhere on the board
VPORT2_OUT: R6.2, U4.2 (IN1-); also elsewhere on the board
VPORT3_OUT: R7.2, U4.13 (IN4-); also elsewhere on the board
VPORT4_OUT: R8.2, U4.9 (IN3-); also elsewhere on the board
VREF: D1.1 (C), R10.1, U5.3 (INA+), U5.5 (INB+), U5.10 (INC+), U5.12 (IND+)

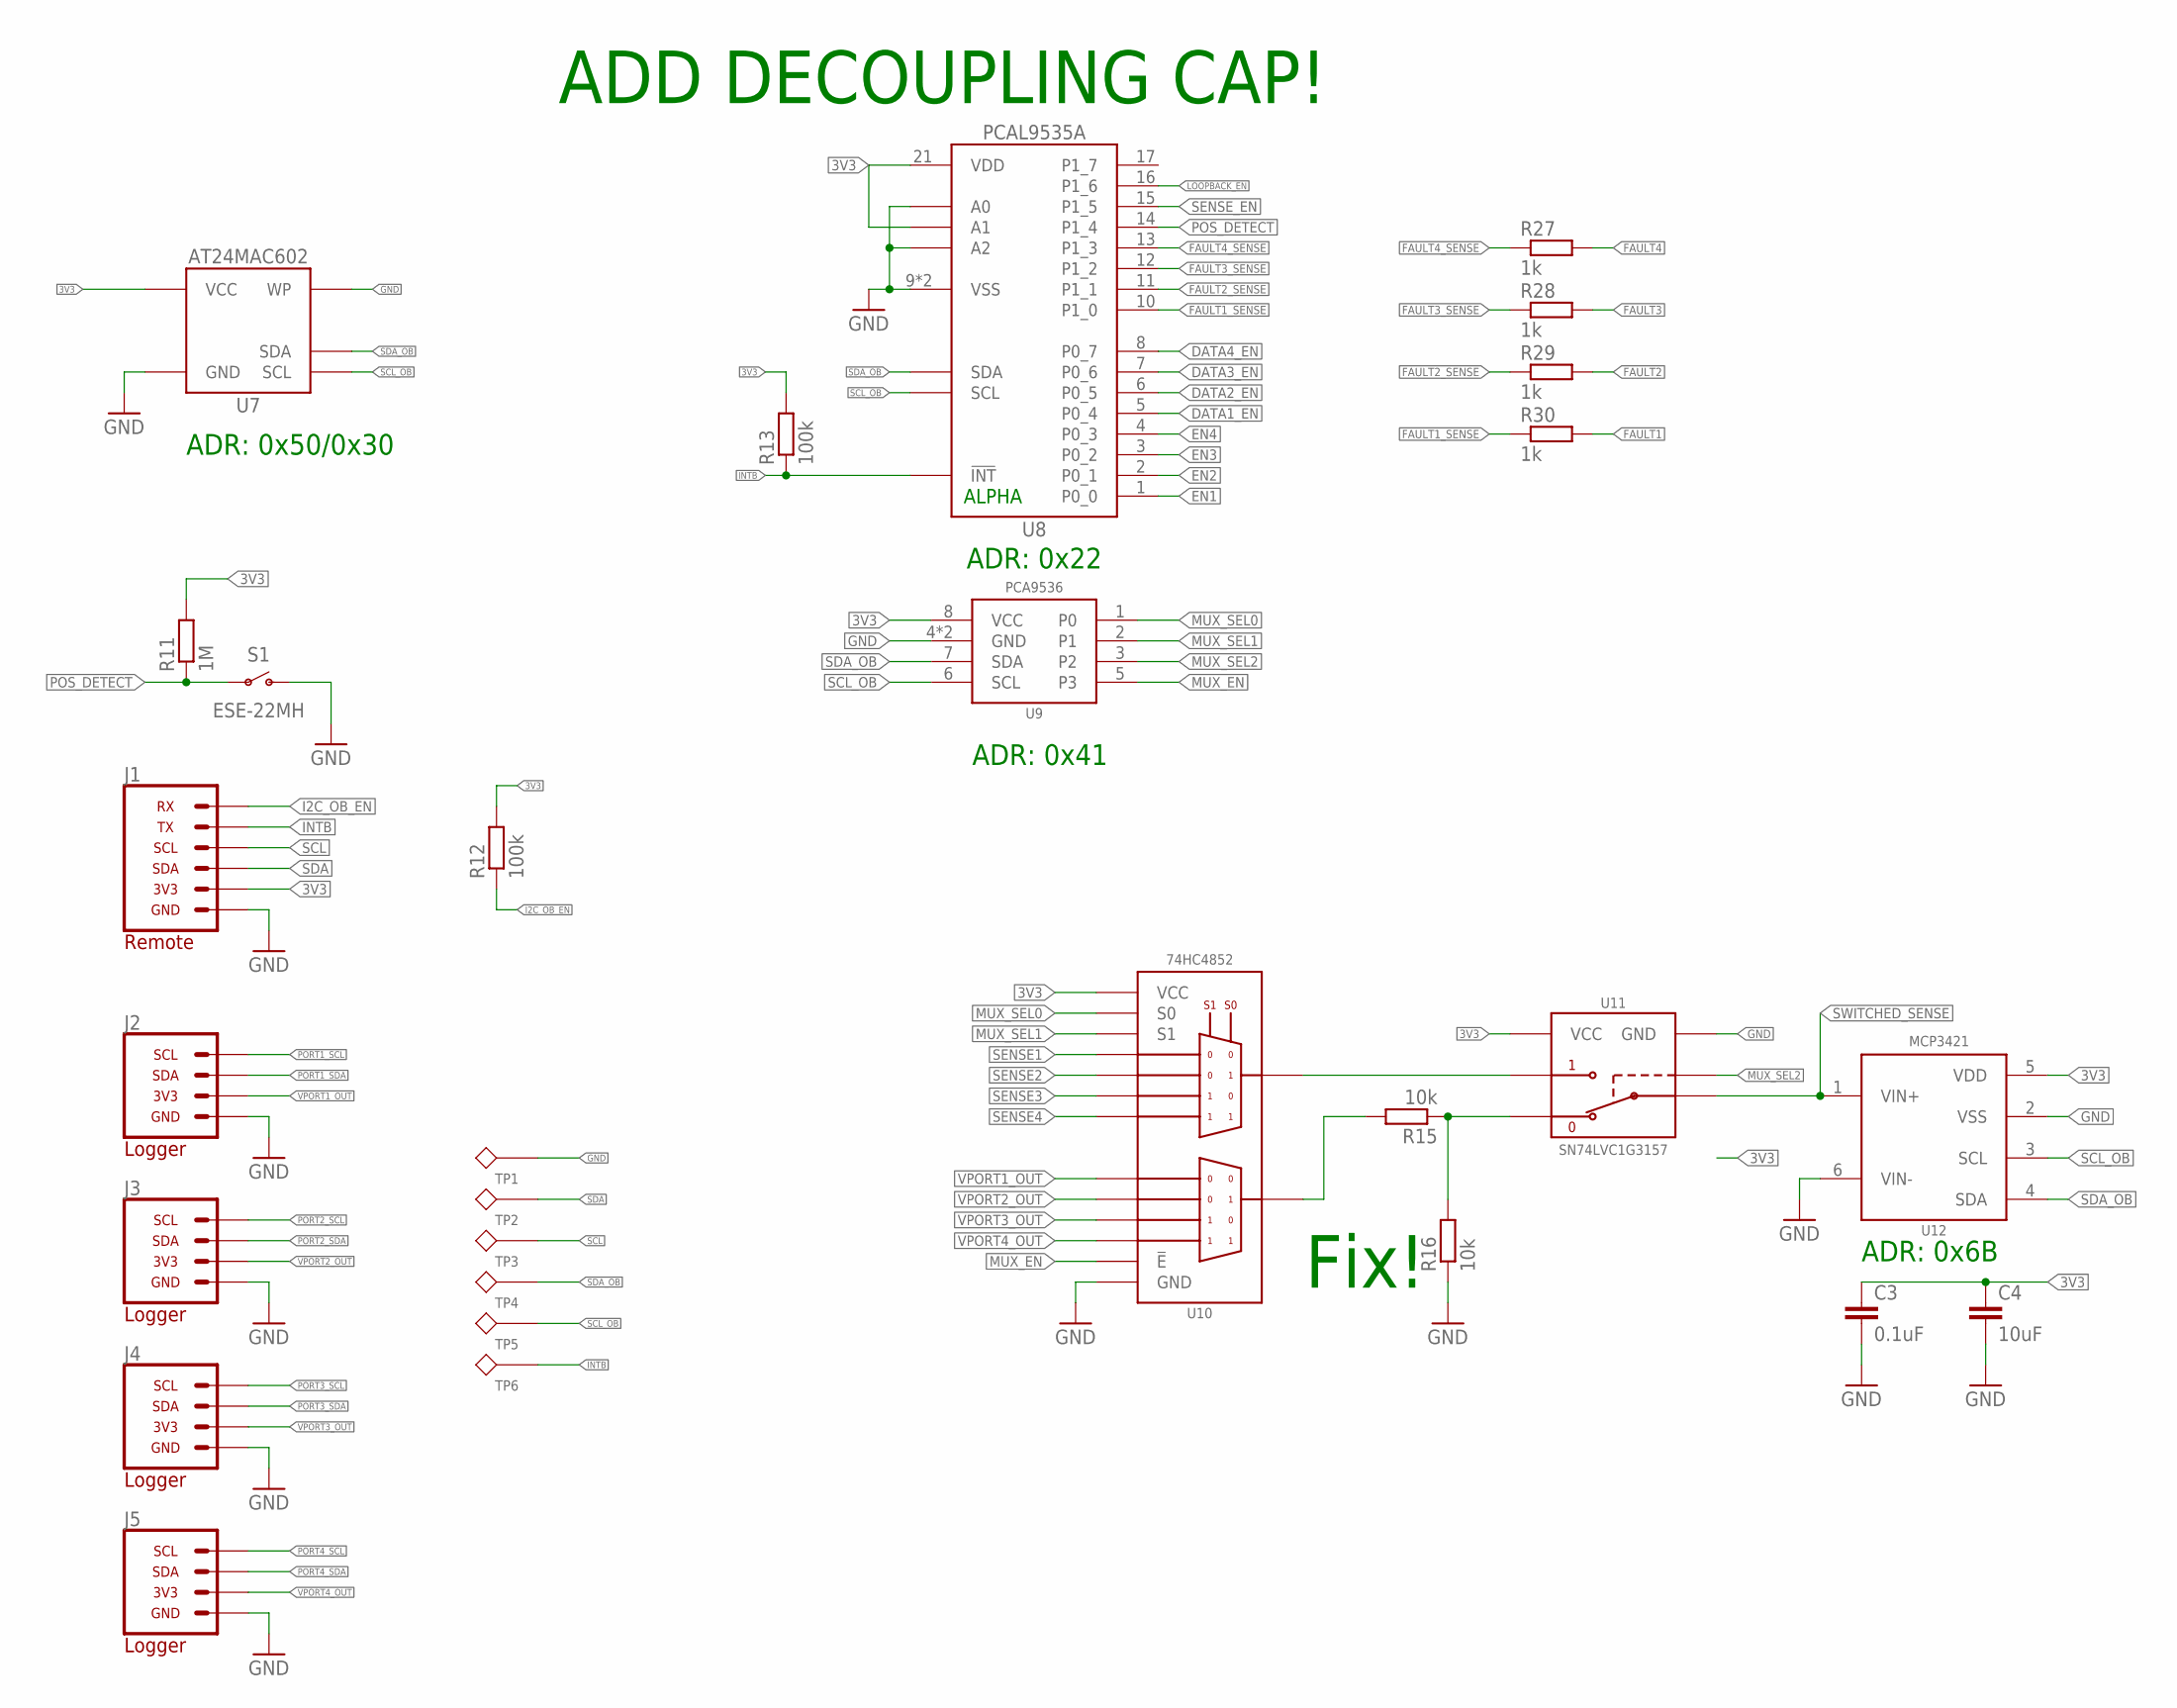
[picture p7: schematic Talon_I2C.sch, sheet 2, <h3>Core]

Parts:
C3: 0.1uF; C0402
C4: 10uF; C0805
J1: CONN_TALON_REMOTE; 1X06_MICROLOCKPLUS
J2, J3, J4, J5: CONN_I2C_LOGGER; 1X04_M8_TE_T404103_BOARDLOCK
R11: 1M; R0402
R12, R13: 100k; R0402
R15, R16: 10k; R0402
R27, R28, R29, R30: 1k; R0402
S1: ESE-22MH
TP1, TP2, TP3, TP4, TP5, TP6: TESTPOINTRCU; TESTPOINT_0603
U7: AT24MAC602SOT23; SOT23-5
U8: PCAL9535AQFN; QFN24
U9: PCA9536DFN; DFN_8_3X3
U10: 74HC4852; VQFN-16
U11: SN74LVC1G3157SC70; DCK_R-PDSO-G6
U12: MCP3421A3; SOT23-6L

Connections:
3V3: C3.1, C4.1, J1.2 (3V3), R11.2, R12.2, R13.2, U7.4 (VCC), U8.21 (VDD), U8.23 (A1), U9.8 (VCC), U10.16 (VCC), U11.5 (VCC), U12.5 (VDD); also elsewhere on the board
DATA1_EN: U8.5 (P0_4); also elsewhere on the board
DATA2_EN: U8.6 (P0_5); also elsewhere on the board
DATA3_EN: U8.7 (P0_6); also elsewhere on the board
DATA4_EN: U8.8 (P0_7); also elsewhere on the board
EN1: U8.1 (P0_0); also elsewhere on the board
EN2: U8.2 (P0_1); also elsewhere on the board
EN3: U8.3 (P0_2); also elsewhere on the board
EN4: U8.4 (P0_3); also elsewhere on the board
FAULT1: R30.2; also elsewhere on the board
FAULT1_SENSE: R30.1, U8.10 (P1_0)
FAULT2: R29.2; also elsewhere on the board
FAULT2_SENSE: R29.1, U8.11 (P1_1)
FAULT3: R28.2; also elsewhere on the board
FAULT3_SENSE: R28.1, U8.12 (P1_2)
FAULT4: R27.2; also elsewhere on the board
FAULT4_SENSE: R27.1, U8.13 (P1_3)
GND: C3.2, C4.2, J1.1 (GND), J2.4 (GND), J3.4 (GND), J4.4 (GND), J5.4 (GND), R16.1, S1.1 (O), TP1.1, U7.2 (GND), U7.5 (WP), U8.9 (VSS), U8.18 (A0), U8.24 (A2), U8.EP (VSS), U9.4 (GND), U9.EP (GND), U10.8 (GND), U10.EP (GND), U11.2 (GND), U12.2 (VSS), U12.6 (VIN-); also elsewhere on the board
I2C_OB_EN: J1.6 (RX), R12.1; also elsewhere on the board
INTB: J1.5 (TX), R13.1, TP6.1, U8.22 (!INT)
LOOPBACK_EN: U8.16 (P1_6); also elsewhere on the board
MUX_EN: U9.5 (P3), U10.6 (!E)
MUX_SEL0: U9.1 (P0), U10.10 (S0)
MUX_SEL1: U9.2 (P1), U10.9 (S1)
MUX_SEL2: U9.3 (P2), U11.6 (S)
unnamed: R15.2, U10.3 (2Z)
unnamed: R15.1, R16.2, U11.3 (B1)
unnamed: U10.13 (1Z), U11.1 (B2)
PORT1_SCL: J2.3 (SCL); also elsewhere on the board
PORT1_SDA: J2.1 (SDA); also elsewhere on the board
PORT2_SCL: J3.3 (SCL); also elsewhere on the board
PORT2_SDA: J3.1 (SDA); also elsewhere on the board
PORT3_SCL: J4.3 (SCL); also elsewhere on the board
PORT3_SDA: J4.1 (SDA); also elsewhere on the board
PORT4_SCL: J5.3 (SCL); also elsewhere on the board
PORT4_SDA: J5.1 (SDA); also elsewhere on the board
POS_DETECT: R11.1, S1.2, U8.14 (P1_4)
SCL: J1.4 (SCL), TP3.1; also elsewhere on the board
SCL_OB: TP5.1, U7.1 (SCL), U8.19 (SCL), U9.6 (SCL), U12.3 (SCL); also elsewhere on the board
SDA: J1.3 (SDA), TP2.1; also elsewhere on the board
SDA_OB: TP4.1, U7.3 (SDA), U8.20 (SDA), U9.7 (SDA), U12.4 (SDA); also elsewhere on the board
SENSE1: U10.12 (1Y0); also elsewhere on the board
SENSE2: U10.14 (1Y1); also elsewhere on the board
SENSE3: U10.15 (1Y2); also elsewhere on the board
SENSE4: U10.11 (1Y3); also elsewhere on the board
SENSE_EN: U8.15 (P1_5); also elsewhere on the board
SWITCHED_SENSE: U11.4 (A), U12.1 (VIN+)
VPORT1_OUT: J2.2 (3V3), U10.1 (2Y0); also elsewhere on the board
VPORT2_OUT: J3.2 (3V3), U10.5 (2Y1); also elsewhere on the board
VPORT3_OUT: J4.2 (3V3), U10.2 (2Y2); also elsewhere on the board
VPORT4_OUT: J5.2 (3V3), U10.4 (2Y3); also elsewhere on the board

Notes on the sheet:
ALPHA
ADD DECOUPLING CAP!
Fix!
ADR: 0x22
ADR: 0x6B
ADR: 0x50/0x30
ADR: 0x41

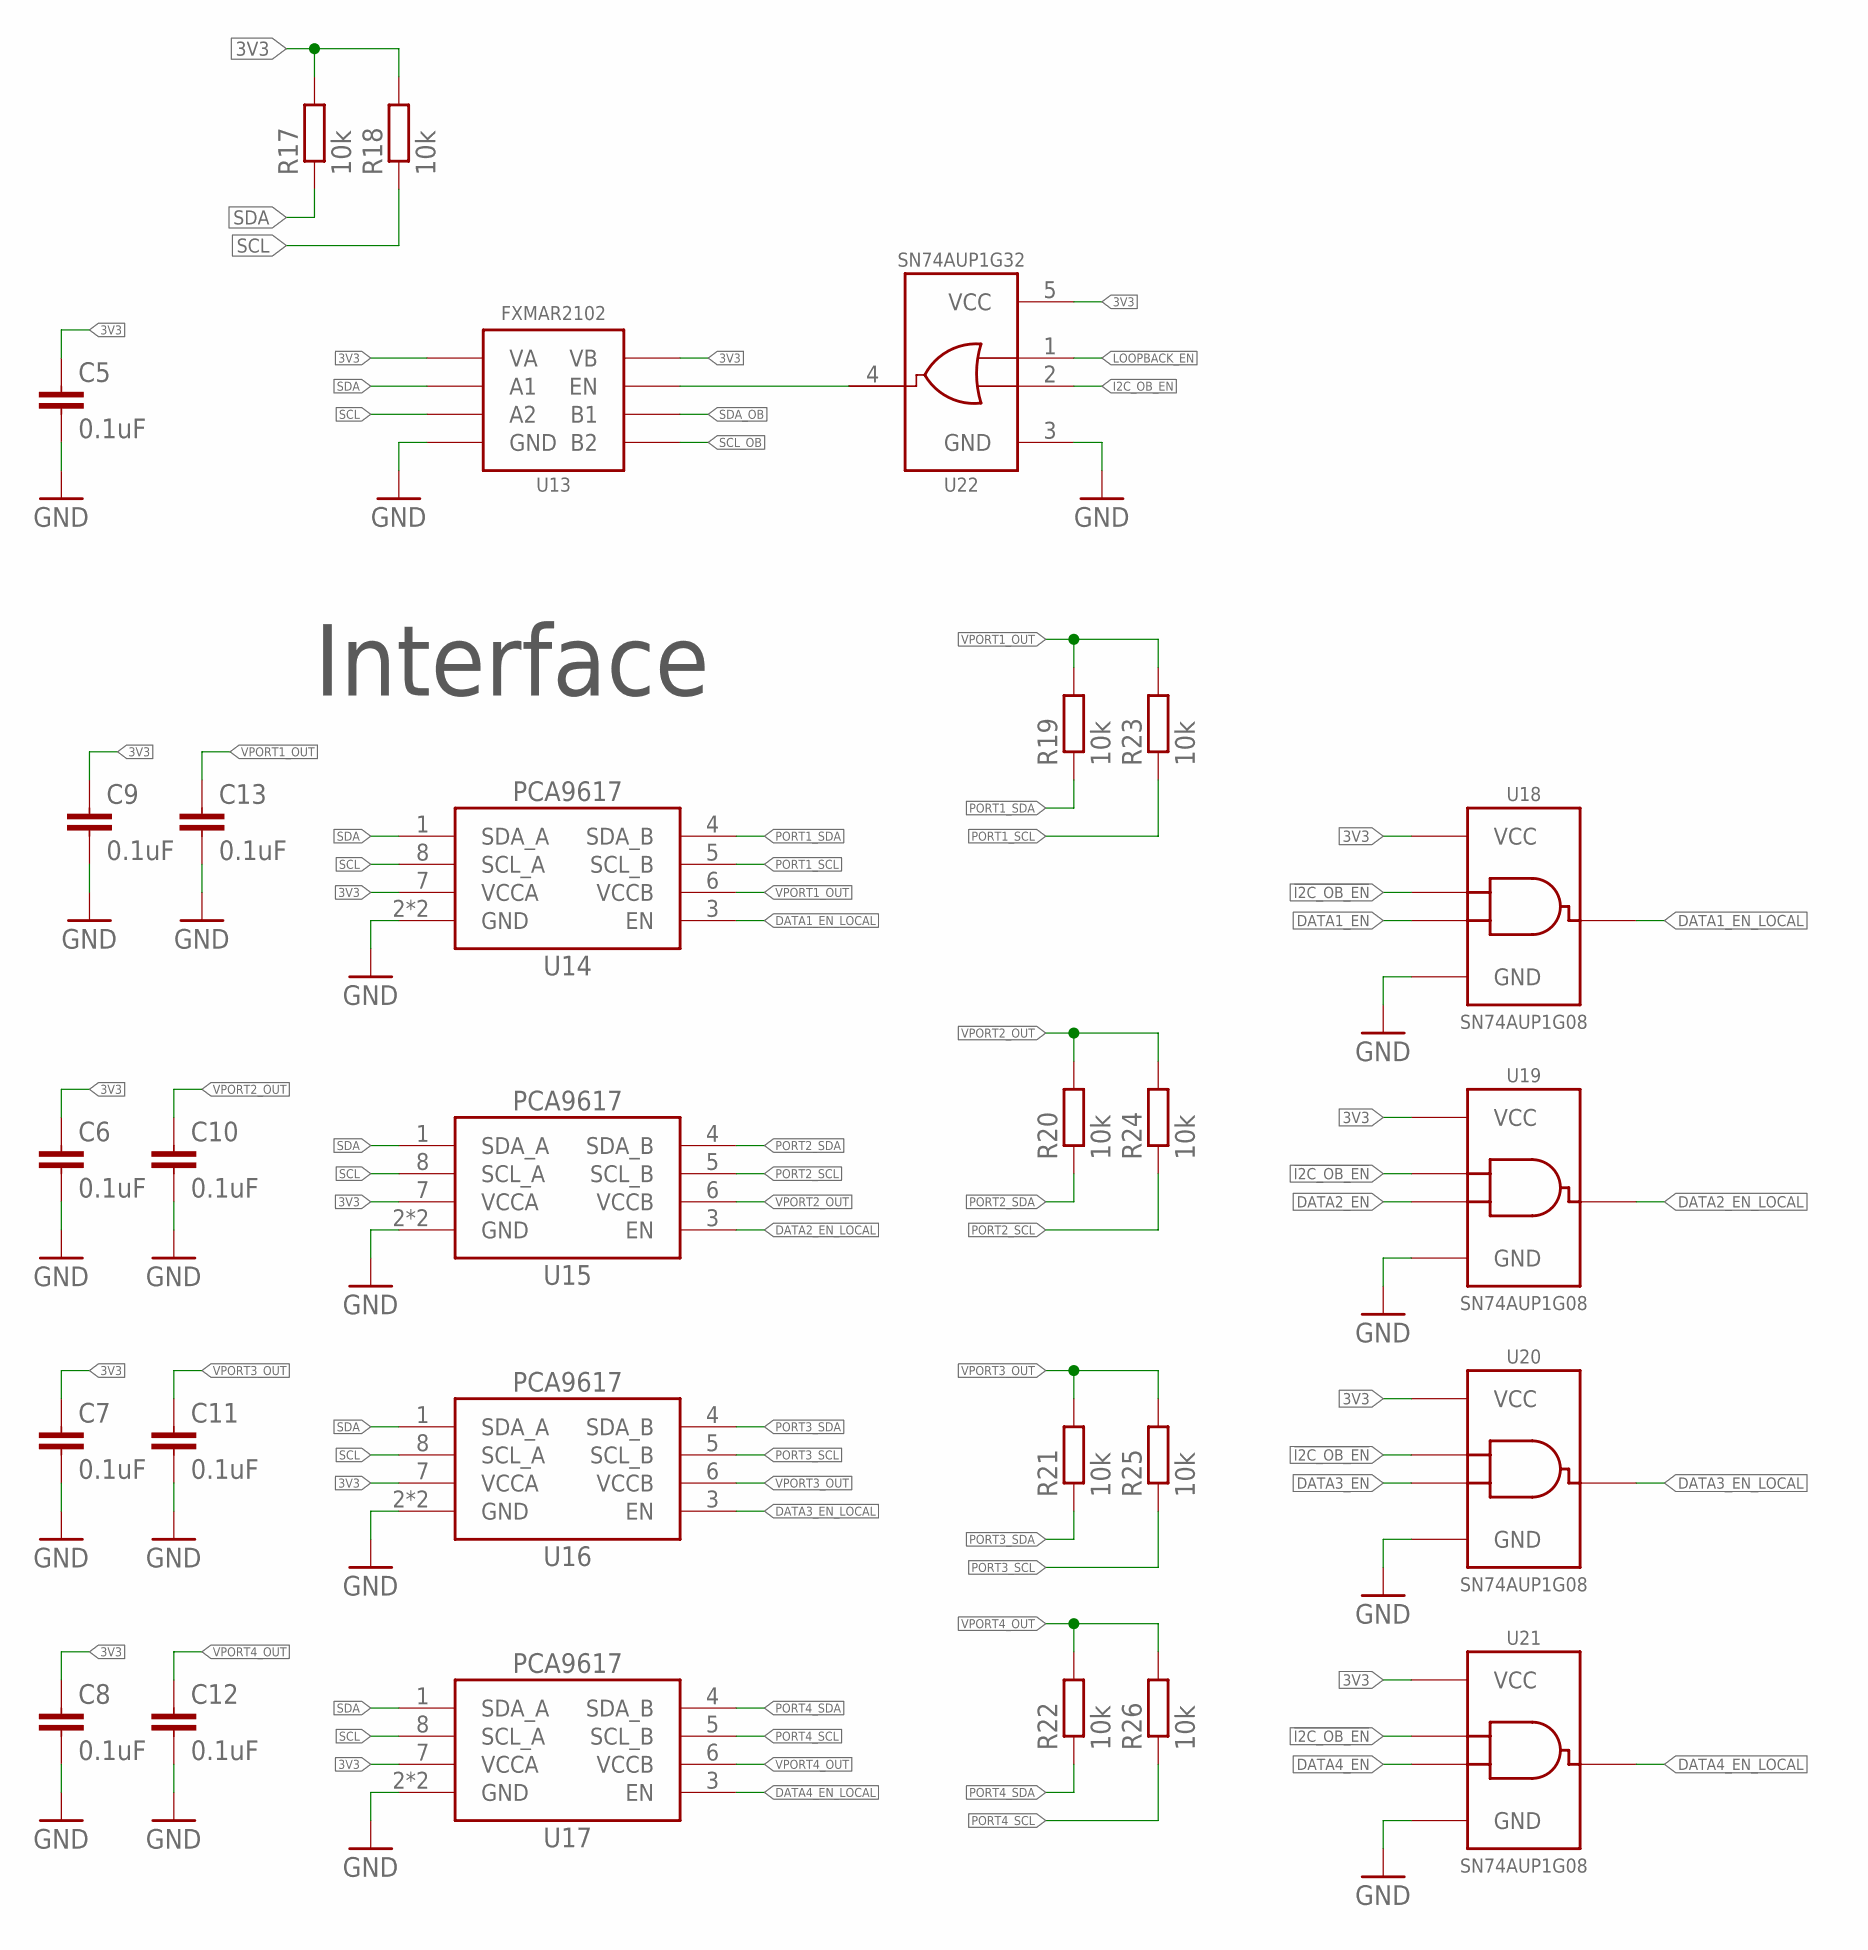
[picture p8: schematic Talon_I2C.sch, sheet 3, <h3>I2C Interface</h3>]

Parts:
C5, C6, C7, C8, C9, C10, C11, C12, C13: 0.1uF; C0402
R17, R18, R19, R20, R21, R22, R23, R24, R25, R26: 10k; R0402
U13: FXMAR2102UMLP; UQFN-8_1.4X1.2
U14, U15, U16, U17: PCA9617WSON; WSON-8_2X3
U18, U19, U20, U21: SN74AUP1G08DCK; DCK_R-PDSO-G5
U22: SN74AUP1G32DCK; DCK_R-PDSO-G5

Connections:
3V3: C5.1, C6.1, C7.1, C8.1, C9.1, R17.2, R18.2, U13.1 (VA), U13.8 (VB), U14.7 (VCCA), U15.7 (VCCA), U16.7 (VCCA), U17.7 (VCCA), U18.5 (VCC), U19.5 (VCC), U20.5 (VCC), U21.5 (VCC), U22.5 (VCC); also elsewhere on the board
!I2C_OB_EN: U18.1 (A), U19.1 (A), U20.1 (A), U21.1 (A); also elsewhere on the board
DATA1_EN: U18.2 (B); also elsewhere on the board
DATA1_EN_LOCAL: U14.3 (EN), U18.4 (Y)
DATA2_EN: U19.2 (B); also elsewhere on the board
DATA2_EN_LOCAL: U15.3 (EN), U19.4 (Y)
DATA3_EN: U20.2 (B); also elsewhere on the board
DATA3_EN_LOCAL: U16.3 (EN), U20.4 (Y)
DATA4_EN: U21.2 (B); also elsewhere on the board
DATA4_EN_LOCAL: U17.3 (EN), U21.4 (Y)
GND: C5.2, C6.2, C7.2, C8.2, C9.2, C10.2, C11.2, C12.2, C13.2, U13.4 (GND), U14.2 (GND), U14.EP (GND), U15.2 (GND), U15.EP (GND), U16.2 (GND), U16.EP (GND), U17.2 (GND), U17.EP (GND), U18.3 (GND), U19.3 (GND), U20.3 (GND), U21.3 (GND), U22.3 (GND); also elsewhere on the board
I2C_OB_EN: U22.2 (B); also elsewhere on the board
LOOPBACK_EN: U22.1 (A); also elsewhere on the board
unnamed: U13.5 (EN), U22.4 (Y)
PORT1_SCL: R23.1, U14.5 (SCL_B); also elsewhere on the board
PORT1_SDA: R19.1, U14.4 (SDA_B); also elsewhere on the board
PORT2_SCL: R24.1, U15.5 (SCL_B); also elsewhere on the board
PORT2_SDA: R20.1, U15.4 (SDA_B); also elsewhere on the board
PORT3_SCL: R25.1, U16.5 (SCL_B); also elsewhere on the board
PORT3_SDA: R21.1, U16.4 (SDA_B); also elsewhere on the board
PORT4_SCL: R26.1, U17.5 (SCL_B); also elsewhere on the board
PORT4_SDA: R22.1, U17.4 (SDA_B); also elsewhere on the board
SCL: R18.1, U13.3 (A2), U14.8 (SCL_A), U15.8 (SCL_A), U16.8 (SCL_A), U17.8 (SCL_A); also elsewhere on the board
SCL_OB: U13.6 (B2); also elsewhere on the board
SDA: R17.1, U13.2 (A1), U14.1 (SDA_A), U15.1 (SDA_A), U16.1 (SDA_A), U17.1 (SDA_A); also elsewhere on the board
SDA_OB: U13.7 (B1); also elsewhere on the board
VPORT1_OUT: C13.1, R19.2, R23.2, U14.6 (VCCB); also elsewhere on the board
VPORT2_OUT: C10.1, R20.2, R24.2, U15.6 (VCCB); also elsewhere on the board
VPORT3_OUT: C11.1, R21.2, R25.2, U16.6 (VCCB); also elsewhere on the board
VPORT4_OUT: C12.1, R22.2, R26.2, U17.6 (VCCB); also elsewhere on the board

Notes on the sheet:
Interface

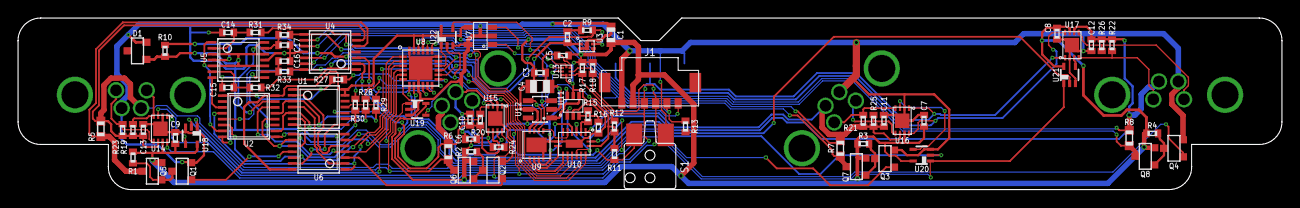
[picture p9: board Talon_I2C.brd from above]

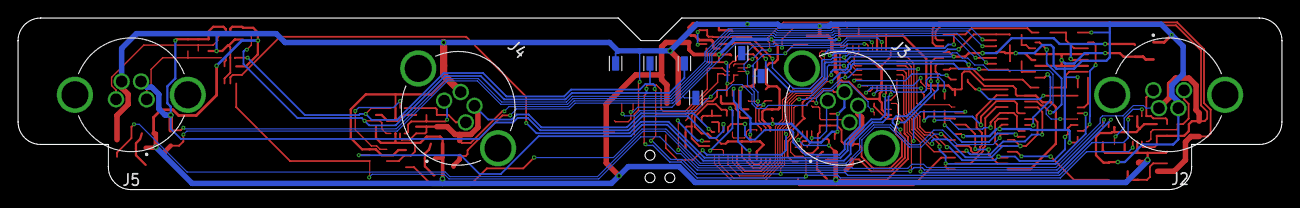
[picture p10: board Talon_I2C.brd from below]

Board: 2 copper layers, 140.0 x 19.0 mm, 93 parts (10 on the bottom side), 83 nets.

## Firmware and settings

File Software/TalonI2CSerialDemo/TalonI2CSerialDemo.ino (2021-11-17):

#include <Wire.h>
 // #include "Adafruit_MCP23008.h"
// #include <Adafruit_MCP23X17.h>
// #include <MCP2301x.h>
#include <Arduino.h>
#include <MCP23018.h>

// #define NUM_MCP2301x_ICs   1

const uint8_t TX = 1;
const uint8_t RX = 0;
const uint8_t FOut = 1;
const uint8_t Dir = 0;

//IO Expander pins
const uint8_t POS_DETECT = 12; 
const uint8_t SENSE_EN = 13;

//IO Sense pins
const uint8_t MUX_EN = 3;
const uint8_t MUX_SEL0 = 0;
const uint8_t MUX_SEL1 = 1;
const uint8_t MUX_SEL2 = 2;

const float VoltageDiv = 3; //Program voltage divider
const float CurrentDiv = 0.243902439; //82mOhm, 50V/V Amp

//Configured for pins on the Particle Boron
//const uint8_t EXT_EN = 8;
//const uint8_t SDA_CTRL = 2;

 const uint8_t I2C_EN = 13;

char ReadArray[25] = {0};

 // Adafruit_MCP23008 io;
// Adafruit_MCP23X17 io;
MCP23018 io(0x22);
// MCP2301x io;

// #define IOEXP_MODE  (IOCON_INTCC | IOCON_INTPOL | IOCON_ODR | IOCON_MIRROR)
// #define ADDRESS      (MCP2301X_CTRL_ID+7)
// #define LED_PIN      D4   // WeMOS D1 & D1 mini
// #define IN_PORT      0
// #define OUT_PORT     1

// #define RELAY_ON      LOW
// #define RELAY_OFF     HIGH
// #define ALL_OFF       ALL_LOW

// #define DIR 0x00
// #define GPIO 0x12
// #define LAT 0x14
// #define PU 0x0C
// #define ADR 0x20

/////////////// HAAR //////////////////////
#include <Dps368.h>
#include <Adafruit_SHT31.h>

Dps368 pressureSense = Dps368(); //Instantiate DPS368 Pressure sensor
Adafruit_SHT31 rhSense = Adafruit_SHT31(); //Instantiate the SHT31 RH/Temp sensor

const uint8_t dps368_oversampling = 7; //Define the oversampling amount for the DPS368 sensor
unsigned long period = 5000; //Number of ms to wait between sensor readings 

////////////// HEDORAH NDIR /////////////
#include "SparkFun_SCD30_Arduino_Library.h" //Click here to get the library: http://librarymanager/All#SparkFun_SCD30
SCD30 airSensor;

///////////// VOLTAGE SENSE /////////////
#include <SparkFun_PCA9536_Arduino_Library.h>
#include <MCP3421.h>

MCP3421 adc(0x6B); //Initialize MCP3421 with A3 address

PCA9536 ioSense;

void setup() 
{
	pinMode(I2C_EN, OUTPUT); 
	digitalWrite(I2C_EN, HIGH); //Turn on external port connection
	Serial.begin(115200);

	Wire.begin();
	SetDefaultPins();
	// SetPinMode();
	// SetPullups();
	// io.digitalWrite(6, HIGH); //Turn on 5V
	// io.digitalWrite(7, HIGH); //Turn on 12V
	// io.digitalWrite(2, LOW); //Enable Data 1
	// io.digitalWrite(3, LOW); //Enable Data 2
	// io.digitalWrite(4, LOW); //Enable Data 3

	
	delay(1000);
	Serial.println("Begin I2C Demo...");
}

void loop() 
{
	// io.pinMode(0, TX, LOW);
	// io.pinMode(0, FOut, LOW);
	// delay(1000);
	// io.pinMode(0, FOut, LOW);
	// io.pinMode(0, TX, HIGH);
	// delay(1000);
	// io.pinMode(0, FOut, HIGH);
	// io.pinMode(0, TX, LOW);
	// delay(1000);
	// io.pinMode(0, FOut, HIGH);
	// io.pinMode(0, TX, HIGH);
	// delay(1000);
	static int ReadLength = 0;
  	String ReadString;
	if(Serial.available() > 0) {
    char Input = Serial.read();

    // Increment counter while waiting for carrage return or newline
    // if(Input != 13 || Input != 10) {
    if(Input != '#' && Input != '!') { //Wait for SDI12 line end or control line end 
      ReadArray[ReadLength] = Input;
      ReadLength++;
    }

    // if(Input == 13 || Input == 10) { // carriage or newline
    if(Input == '!') { //SDI12 line ending
		ReadArray[ReadLength] = Input; //Append final character
		ReadLength++;

		ReadString = String(ReadArray);
		ReadString.trim();
		memset(ReadArray, 0, sizeof(ReadArray));
		ReadLength = 0;
		int Pin = (ReadString.substring(0,1)).toInt(); //Grab the pin to operate on

		Serial.print(">");
		Serial.println(ReadString); //Echo back to serial monitor

		switch(Pin) { //Call the interface function for the appropriate sensor to test
			case 0:
				VoltageSense();
				break;
			case 1:
				Sensor1();
				break;
			case 2:
				Sensor2();
				break;
			case 3:
				Sensor3();
				break;
			case 4:
				Sensor4();
				break;
			default:
				Serial.println(">You didn't say the magic word!"); 
		}
		
	}
	//Format - ppCs#
	//pp - two digit pin number (base 10)
	//C - command ('M' - Mode, 'R' - Read, 'W' - Write)
	//s - state (0 - Output/Off, 1 - Input/On), required only for write and mode operations 
	if(Input == '#') { //Control line ending
		ReadString = String(ReadArray);
		ReadString.trim();
		memset(ReadArray, 0, sizeof(ReadArray));
		ReadLength = 0;
		int Pin = (ReadString.substring(0,2)).toInt(); //Grab the pin to operate on
		String Operation = ReadString.substring(2,3); //Grab the middle char
		int State = (ReadString.substring(3,4)).toInt(); //Grab the state to set
		int Result = 0; //Used to grab result of either setting of pin mode or response from a read

		digitalWrite(I2C_EN, LOW); //Turn off external port connection
		if(Operation.equals("M")) { //if call is for pinmode setting
			Result = io.pinMode(Pin, !State); //Use inverse of state to corespond with 1 = input, 0 = output
		}
		
		if(Operation.equals("R")) { //If call is for digital read
			Result = io.digitalRead(Pin);
		}

		if(Operation.equals("W")) { //If call is for digital write
			Result = io.digitalWrite(Pin, State);
		}
		digitalWrite(I2C_EN, HIGH); //Turn on external port connection
		// while(Serial.peek() != '\n'); //Wait for new command
		// String NewCommand = Serial.readStringUntil('\n');
		Serial.print(">");
		Serial.println(ReadString); //Echo back to serial monitor
		Serial.print(">");
		Serial.println(Result); //Return various result 
	}
	// GetAddress();
	// delay(5000);

	}
}

void VoltageSense() //Voltage sense (AKA Sensor0)
{
	Serial.print(">Voltage Sense:\n");
	digitalWrite(I2C_EN, LOW); //Turn off external I2C
	io.digitalWrite(SENSE_EN, HIGH); //Make sure sense power is turned on
	ioSense.begin(); //Initalize voltage sensor IO expander
	for(int i = 0; i < 4; i++) { //Set all pins to output
		ioSense.pinMode(i, OUTPUT); 
	}
	ioSense.digitalWrite(MUX_EN, HIGH); //Turn MUX on 
	int SenseError = adc.Begin(); //Initialize ADC 
	if(SenseError == 0) { //Only proceed if ADC connects correctly
		adc.SetResolution(18); //Set to max resolution (we paid for it right?) 

		ioSense.digitalWrite(MUX_SEL2, LOW); //Read voltages
		for(int i = 0; i < 4; i++){ //Increment through 4 voltages
			ioSense.digitalWrite(MUX_SEL0, i & 0b01); //Set with lower bit
			ioSense.digitalWrite(MUX_SEL1, (i & 0b10) >> 1); //Set with high bit
			delay(1); //Wait for voltage to stabilize
	  		Serial.print("\tPort");
	  		Serial.print(i);
	  		Serial.print(":");
	  		Serial.print(adc.GetVoltage(true)*VoltageDiv, 6); //Print high resolution voltage
	  		Serial.print(" V\n");  
		}
		ioSense.digitalWrite(MUX_SEL2, HIGH); //Read currents
		for(int i = 0; i < 4; i++){ //Increment through 4 voltages
			ioSense.digitalWrite(MUX_SEL0, i & 0b01); //Set with lower bit
			ioSense.digitalWrite(MUX_SEL1, (i & 0b10) >> 1); //Set with high bit
			delay(1); //Wait for voltage to stabilize
	  		Serial.print("\tPort");
	  		Serial.print(i);
	  		Serial.print(":");
	  		Serial.print(adc.GetVoltage(true)*CurrentDiv*1000, 6); //Print high resolution current measure in mA
	  		Serial.print(" mA\n");  
		}
	}
	else Serial.print("\tFAIL!\n");
	digitalWrite(I2C_EN, HIGH); //Turn on external I2C
}


void Sensor1() 
{
	// Serial.println(">Spector1");
	/////////////// SETUP /////////////////////
	digitalWrite(I2C_EN, LOW); //Turn on external I2C
	uint8_t error_dps368 = 0; //DEBUG! FIX! Change library to return stuff properly
	pressureSense.begin(Wire); //Initialize DPS368 sensor //DEBUG! FIX! Change library to return stuff properly
	uint8_t error_sht31 = rhSense.begin(0x44); //Initialize SHT31 sensor
	
	Serial.println(">Haar Status:"); //Print resulting sensor status 
	Serial.print("\tDPS368: "); 
	if(error_dps368 == 0) Serial.print("PASS\n"); //Print error grabbed from sensor
	else Serial.print("FAIL!\n"); //Fail if result is not 0
	Serial.print("\tSHT31: ");
	if(error_sht31 == 1) Serial.print("PASS\n"); //Print error grabbed from sensor
	else Serial.print("FAIL!\n"); //Fail if result is 0

	///////////////// RUN ////////////////////
	float temp_dps368; //Storage for temp measurement from DPS368 
  	float pressure; //Storage for pressure measurment from DPS368
  	

	int16_t error1 = pressureSense.measureTempOnce(temp_dps368, dps368_oversampling); //Grab new temp values [°C]
	int16_t error2 = pressureSense.measurePressureOnce(pressure, dps368_oversampling); //Grab new pressure values [Pa]
	pressure = pressure/100.0f; //Convert from Pa to mBar, because Pa is a stupid unit, and hPa is more stupid. 

	float humidity = rhSense.readHumidity(); //Grab new humidity values [%]
	float temp_sht31 = rhSense.readTemperature(); //Grab new temp values [°C]
	digitalWrite(I2C_EN, HIGH); //Turn off external I2C

	Serial.print("\tTemp (SHT31): "); Serial.print(temp_sht31, 4); Serial.print(" °C\t"); //Print temp to 4 decimal places
	Serial.print("Temp (DPS368): "); Serial.print(temp_dps368, 2); Serial.print(" °C\t"); //Print temp to 2 decimal places
	Serial.print("Pressure: "); Serial.print(pressure, 2); Serial.print(" mBar\t"); //Print pressure to 2 decimal places
	Serial.print("Humidity: "); Serial.print(humidity, 2); Serial.print(" %\n"); //Print humidity to 2 decimal places
}

void Sensor2() 
{
	// Serial.println(">Spector2");
	Wire.begin();

	Serial.println(">Hedorah Status:");
	Serial.print("\tSCD30: ");
	if (airSensor.begin() == false)
	{
		Serial.print("FAIL!\n");
	}
	else {
		Serial.print("PASS\n");
		Serial.print("\t...");
		unsigned long LocalTime = millis();
		while(millis() - LocalTime < 10000){
			if (airSensor.dataAvailable())
			{
				Serial.print("\tCO2: "); //Print sensor CO2 reading
				Serial.print(airSensor.getCO2());
				Serial.print(" PPM\t");

				Serial.print("Temp:"); //Print sensor temp
				Serial.print(airSensor.getTemperature(), 1);
				Serial.print(" °C\t");

				Serial.print("RH:"); //Print sensor RH
				Serial.print(airSensor.getHumidity(), 1);
				Serial.print(" %\n");
				break; //Exit while loop
			}
		}
		if(millis() - LocalTime > 10000) Serial.print("\tERROR: Timeout\n"); //Report timeout error if time has elapsed on exit
	}

}

void Sensor3() 
{

}

void Sensor4() 
{

}

void SetDefaultPins()
{
	digitalWrite(I2C_EN, LOW); //Turn off external I2C
	for(int i = 0; i < 8; i++) { //Enable all power, then all data
		io.pinMode(i, OUTPUT);
		io.digitalWrite(i, HIGH);
	} 

	for(int i = 8; i < 12; i++) { //Set FAULT lines as input pullups
		io.pinMode(i, INPUT_PULLUP);
	}

	io.pinMode(POS_DETECT, INPUT); //Set position detect as normal pullup (has external pullup)
	io.pinMode(SENSE_EN, OUTPUT); //Set sense control as output
	io.digitalWrite(SENSE_EN, HIGH); //Default sense to on 
	digitalWrite(I2C_EN, HIGH); //Turn on external I2C
}

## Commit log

2021-10-07 Initial design via copy from SDI-12 Talon
    Added the initial design as a copy from the SDI-12 Talon in order to utilize the existing layout of the current limit sub-circuit, etc
    [Talon_I2C.brd, Talon_I2C.sch]
2021-10-08 Copper layout done
    [Talon_I2C.brd, Talon_I2C.sch]
2021-10-08 Generated gerbers for v0.0
    Ready for final review
    [Talon_I2C.brd, Talon_I2C.sch]
2021-10-12 Layout, gerbers and BoM for v0.0 - submitted to fab
    [Talon_I2C.brd, Talon_I2C.sch, Talon_I2C_0v0_BoM.csv]
2021-10-14 Generated documentation for v0.1 quote - NAMING ERROR
    Note: These documents reflect the changes made fro v0.0 -> v0.1, but the marking on the board was not updated, so it still reads v0.0, despite being updated from the original version.
    [Talon_I2C_0v1_BoM.csv]
2021-10-14 Fixed board silkscreen issue - NAMING ERROR
    Corrected the naming error on the board and generated new gerbers
    [Talon_I2C.brd]
2021-11-22 Updates for v1.0, sent to fab
    Made fixes for v1.0:
    - Fixed bypass control
    - Added filter lines (clitch protection) to sense lines
    - Flipped Talon connector port pinout
    - Moved MUX (U9/U10) to prevent soldering issues
    - Moved U6 to prevent bumping
    [Talon_I2C.brd, Talon_I2C.sch]
2021-11-22 Updated paste for v1.0
    [Talon_I2C.brd]
2021-11-23 v1.1 updates
    Moved port 1 and port 4, sent to fab
    [Talon_I2C.brd, Talon_I2C.sch]
2021-12-09 Add dimension drawings
    [Talon_I2C.brd]
2021-12-09 Add BoM for v1.1
    [Talon_I2C_1v1_BoM.csv]
2021-12-09 Add mechanical files for v1.1
    [Talon_I2C_1v1.STL, Talon_I2C_1v1.dxf]
2021-12-10 v2.0 update
    Fixed physical overlap in current limit circuit, fixed connector pinout
    [Talon_I2C.brd, Talon_I2C.sch]
2022-04-06 Part number updates
    [Talon_I2C.brd, Talon_I2C.sch, Talon_I2C_2v0_BoM.csv]
2022-04-22 Updated EEPROM part
    [Talon_I2C.brd, Talon_I2C.sch, Talon_I2C_2v0_BoM_2022-04-06.csv]
2022-04-25 v2.1 updates
    Updates made to schematic and layout, boards sent to fab
    [Talon_I2C.brd, Talon_I2C.sch]
2024-09-01 Updated README and board images
2024-11-02 Added production info
    [MainLogger_1v4_BoM.ods, Talon_I2C_2v1_Bom_2022-05-02.csv]

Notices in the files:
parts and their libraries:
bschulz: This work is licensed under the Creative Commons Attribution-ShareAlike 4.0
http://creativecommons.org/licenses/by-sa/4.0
